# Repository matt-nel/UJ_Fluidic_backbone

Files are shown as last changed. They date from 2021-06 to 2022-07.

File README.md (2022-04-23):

# **UJ Fluidic Backbone**

This software provides a controller for low-cost, open-source chemistry equipment. The fluidic backbone uses Commanduino Arduino-based robots using Python scripts. The software provides an object-oriented interace that correlates to the equipment, broken down into module objects with attached device objects. 

The robot can be run manually using the GUI or by loading XDL documents that describe a chemical synthesis. 

https://croningroup.gitlab.io/chemputer/xdl/standard/index.html

The robot can be run in conjuction with the MC_Labserver (https://github.com/Pajables/MC_Labserver), which allows the user to send reactions to a number of attached robots and tracks reaction data. 

## **Installation**

To use the robot, we need to set up software set up on computer and an Arduino. I'll run through all of that here.

First, get the robot's software. On the Github page, click on the green button on the top right and select "Download Zip" from the menu. Extract the contents of that zip file to somewhere on your computer. Click in the address bar and copy the path to where you extracted the files.

### **Python**

The robot has been tested extensively with Python 3.8.5. You can install Python 3.8.5 using the link that follows. It is recommended that you add Python to your Path variables (Keep an eye on the options in the installer). 

https://www.python.org/downloads/release/python-385/

### **Robot software installation**

The easiest way to install the software is to use the `pip` tool in the command prompt (Windows) or terminal (Unix). Use the path we copied earlier for [PATH]. 

```
cd [PATH]
pip install .
```

### **Commanduino**

 Commanduino is a library created by the Cronin Group at the University of Glasgow for controlling Arduino microcontrollers using Python. This robot uses a modified version of the Commanduino library available at:

https://github.com/Pajables/commanduino

To install, download the zip and extract the files to a folder on your computer, I would recommend C:/Users/your_user_name/your_folder for Windows users. Like before, copy the address where you extracted the folder. Open a terminal window, you'll notice that the text to the left of the cursor shows the directory you're currently working within. We need to get the directory that contains commanduino. 

`cd [PATH] `

Now install using pip

`pip install .`

Commanduino is set up!

### **OpenCV** (optional)

OpenCV is a open-source C++ library for computer vision. Required if you will need a camera. 

Windows:

https://opencv.org/releases/

Linux:

Open a terminal and use your favourite package manager to install OpenCV:

`sudo apt install python3-opencv`

### **Arduino IDE and libraries**

To set up the firmware on the Arduino, first download the Arduino IDE at:

https://www.arduino.cc/en/software

The required libraries for the Arduino code can be found in the UJ_Fluidic_backbone repo under: 

`./fluidic_backbone_arduino/commanduino_libraries/`

Please copy the contents of that folder into your Arduino library folder. For Windows users, this is likely

`Documents/Arduino/libraries`

### **Arduino firmware**

Once the Arduino libraries are set up, use the Arduino IDE to upload the firmware within `./fluidic_backbone_arduino/`. Open the Fluidic_backbone_arduino.ino file, set the board and port settings using the tools menu, then click on Upload. This will set the Arduino up to send and receive commands using Commanduino. 

## First-time setup

To first configure the robot, please run the setup GUI. This program will allow you to configure the software for the specific hardware setup you are using.

1. Run `python setup_GUI.py` using the terminal.
2. If a button for an Arduino is available, click on that. Otherwise, write the name of the serial port you will be using in the field, and click "Accept".
3. Click on **"Configure modules"**, then enter the number of valves and syringes into the pop ups that appear.
4. The next screen will show the available valves. Each port has a dropdown where you can select the type of module that is connected to that port. For each port you have connected, select the corresponding item in the dropdown.
5. Once you have selected modules for each used port, click on the buttons for each used port to configure the module. The configuration options will change based on the module you have selected. Once configuration for the port is complete, the button will turn green.
6. Once you have configured all the ports, click **"Accept"**
7. In the main window, click **"Create config"**, then exit the or click "Run Fluidic Backbone" on the right hand side. 

Alternatively, open a terminal and use `cd` browse to the directory where you unzipped the UJ_Fluidic_backbone repo. Use the command `python main.py` to start the robot.

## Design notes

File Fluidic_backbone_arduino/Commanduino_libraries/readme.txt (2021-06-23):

Modified versions of the Arduino-CommandHandler and Arduino-Commandtools libraries.

Copy these files to your Arduino libraries folder to use them in the sketch.

For more information on installing libraries, see: http://www.arduino.cc/en/Guide/Libraries

Links to original repositories:

https://github.com/croningp/Arduino-CommandTools

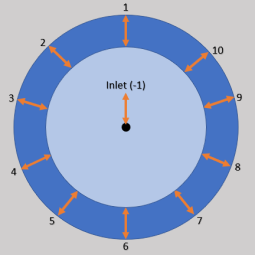
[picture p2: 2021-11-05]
src/UJ_FB/valve.png

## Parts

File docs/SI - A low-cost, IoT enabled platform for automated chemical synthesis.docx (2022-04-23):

Supplementary information: A low-cost, IoT enabled platform for automated chemical synthesis

Matthew Nela, Reinout Meijboom^b, and Andre L. Nela

aDepartment of Mechanical Engineering, University of Johannesburg, PO Box 524, Auckland Park 2006, Johannesburg, South Africa.

^bDepartment of Chemical Sciences, University of Johannesburg, PO Box 524, Auckland Park 2006, Johannesburg, South Africa. Tel.: +27 11 559 2367; Fax.: +27 11 559 2819. E-mail: andren@uj.ac.za

# 1. UJ_FB Design information

## 1.1 Bill of materials

Bill of materials
Part number | QTY | Description | Price (ea) | Total Price | Supplier | Product link
Robot
RB-01 | 1 | Arduino MEGA 2560 microcontroller board | R299.95 | R299.95 | 3D Printing Store | https://www.3dprintingstore.co.za/centurionstore/catalog/product/view/id/1909
RB-02 | 1 | RAMPS 1.4 3D printing expansion board | R199.95 | R199.95 | 3D Printing Store | https://www.3dprintingstore.co.za/centurionstore/catalog/product/view/id/967
RB-03 | 4 | DRV8825 stepper driver with heat sink | R99.95 | R399.80 | 3D Printing Store | https://www.3dprintingstore.co.za/centurionstore/catalog/product/view/id/1113
RB-04 | 1 | Teflon tubing 1/8 in' OD, 1/16 in' ID, 50 ft length | R2 652.65 | R2 652.65 | Analytical Sales & Services | https://www.analytical-sales.com/product/teflon-tubing-1-8-od-x-1-16-id-x-50/
RB-05 | 1 | Raspberry Pi 4 Model B 2GB Kit | R1 169.50 | R1 169.50 | PiShop | https://www.pishop.co.za/store/raspberry-pi_0/raspberry-pi4-model-b-2gb-blackgrey-official-case-essentials-kit-boxed-white-power-supply
RB-06 | 1 | Raspberry Pi Camera Board V2 | R499.00 | R499.00 | PiShop | https://www.pishop.co.za/store/raspberry-pi-camera-board-v2-8mp1080p?keyword=camera&category_id=0
RB-07 | 1 | Syringe pump assembly
RB-08 | 1 | Selector valve assembly
RB-09 | 2 | M3x8 mm bolt
| | | Total | R5 220.85
Valves
SV-01 | 2 | C25-618010 10 position manual selector valve for 1/4-28 fittings | R11 330.00 | R22 660.00 | Analytical Sales & Services | https://www.vici.com/cval/c25-8.php
SV-02 | 2 | NEMA 17 42x42x40 mm stepper motor, 1.8°/step, 1.7 A current/phase, 0.4 Nm holding torque | R269.95 | R539.90 | 3D Printing Store | https://www.3dprintingstore.co.za/centurionstore/stepper-motor-nema-17-x-40mm-1-8-deg-step.html
SV-02 | 2 | KY0024 Linear Hall-Effect sensor development board | R24.72 | R49.44 | Mantech | https://www.mantech.co.za/ProductInfo.aspx?Item=15M4835
SV-03 | 1 | 200 mm jumper leads | R0.54 | R0.54 | Mantech | https://www.mantech.co.za/ProductInfo.aspx?Item=15M5046-A
SV-04 | 10 | N35 Neodymium magnet disk | R5.04 | R50.40 | Mantech | https://www.mantech.co.za/ProductInfo.aspx?Item=15M0681-A
SV-05 | 8 | M3x10 pan head | R0.99 | R7.92 | RS Components | https://za.rs-online.com/web/p/machine-screws/0526956
SV-06 | 8 | M4 stainless steel hex nut | R1.08 | R8.64 | RS Components | https://za.rs-online.com/web/p/hex-nuts/0189579
SV-07 | 2 | M4x30 Cheese head steel slot | R1.34 | R2.68 | RS Components | https://za.rs-online.com/web/p/machine-screws/5466275
SV-08 | 6 | M4x35 Cheese head steel slot | R1.42 | R8.52 | RS Components | https://za.rs-online.com/web/p/machine-screws/9087769
SV-09 | 2 | Valve mount
SV-10 | 4 | ¼-28 Bolt
SV-11 | 2 | Driver gear
SV-12 | 2 | Driven gear
SV-13 | 4 | 6x21 mm round bar
SV-14 | 8 | M3x8 mm grub screw | R4.508 | R36.06 | RS Components | https://za.rs-online.com/web/p/grub-screws-set-screws/1247389
SV-15 | 4 | 6 x19x6 mm Deep groove ball bearing | R55.1 | R220.04 | RS Components | https://za.rs-online.com/web/p/ball-bearings/6189913/?sra=pstk
SV-16 | 2 | Gearbox bottom
SV-17 | 2 | Gearbox top
SV-18 | 8 | M3 hex nut | R0.34 | R4.76 | 3D Printing Store | https://za.rs-online.com/web/p/hex-nuts/0560293
| | | Total | R23 589.04
Syringe Pumps
SP-01 | 2 | NEMA 17 42x42x40 mm stepper motor, 1.8°/step, 1.7 A current/phase, 0.4 Nm holding torque | R269.95 | R539.90 | 3D Printing Store | https://www.3dprintingstore.co.za/centurionstore/stepper-motor-nema-17-x-40mm-1-8-deg-step.html
SP-02 | 2 | Mechanical endstop 90° version | R24.95 | R49.90 | 3D Printing Store | http://www.3dprintingstore.co.za/electronics/mechanical-endstop-90-version/
SP-03 | 2 | TCST2103 Gap Sensor with phototransistor output | R17.44 | R34.88 | Mantech | https://www.mantech.co.za/ProductInfo.aspx?Item=35M4257
SP-04 | 2 | LM393 dual voltage comparator | R11.72 | R23.44 | Mantech | https://www.mantech.co.za/ProductInfo.aspx?Item=15M6164
SP-05 | 4 | Stainless steel rod 6 mm diameter 140 mm | R9.11 | R36.44 | RS Components | https://za.rs-online.com/web/p/metal-bars-metal-rods/0682826/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
SP-06 | 2 | TR8x8 lead screw 115 mm | R50.00 | R100.00 | 3D Printing Store | https://www.3dprintingstore.co.za/centurionstore/catalog/product/view/id/1213
SP-07 | 4 | LM6UU linear bearing pair | R39.00 | R156.00 | 3D Printing Store | https://www.3dprintingstore.co.za/centurionstore/catalog/product/view/id/1009
SP-08 | 2 | Tr8x8 brass nut | R39.95 | R79.90 | 3D Printing Store | https://www.3dprintingstore.co.za/centurionstore/catalog/product/view/id/1166
SP-09 | 2 | Rigid coupling 5-8 mm | R69.95 | R139.90 | 3D Printing Store | https://www.3dprintingstore.co.za/centurionstore/catalog/product/view/id/1659
SP-10 | 20 | M3x20mm bolt | R0.85 | R17.00 | 3D Printing Store | https://za.rs-online.com/web/p/machine-screws/0560625
SP-11 | 14 | M3x6 mm bolt | R0.32 | R4.48 | 3D Printing Store | https://za.rs-online.com/web/p/machine-screws/0560580
SP-12 | 14 | M3 hex nut | R0.34 | R4.76 | RS Components | https://za.rs-online.com/web/p/hex-nuts/0560293
SP-13 | 2 | Hamilton 1010TLL Gastight syringe PTFE luer lock | R1 791.00 | R3 582.00 | Sigma Aldrich | https://www.sigmaaldrich.com/ZA/en/product/sial/21000u?context=product
SP-14 | 2 | Pump body | - | - | - | -
SP-15 | 2 | Pusher Block | - | - | - | -
SP-16 | 2 | Syringe holder | - | - | - | -
SP-17 | 2 | Slotted disk | - | - | - | -
SP-18 | 2 | M3x8 mm bolt | R0.6052 | R1.21 | RS Components | https://za.rs-online.com/web/p/machine-screws/9087661
| | | Total | R4 768.60
Reactor
RCT-01 | 1 | Rostock Delta MK3 Round heated bed | R329.95 | R329.95 | DIY Electronics | https://www.diyelectronics.co.za/store/beds-heaters/1532-rostock-delta-mk3-round-heated-bed.html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
RCT-02 | 2 | 12 V 4010 Axial Fan | R69.95 | R139.9 | DIY Electronics | https://www.diyelectronics.co.za/store/thermistors/630-thermistor-100k-1-ntc-pre-wired.html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
RCT-03 | 1 | 100K Thermistor | R24.95 | R24.95 | DIY Electronics | https://www.diyelectronics.co.za/store/thermistors/630-thermistor-100k-1-ntc-pre-wired.html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
RCT-04 | 4 | Neodymium N42 Rectangular Magnet | R14.95 | R59.80 | DIY Electronics | https://www.diyelectronics.co.za/store/magnets/1308-neodymium-n42-magnets-rectangular-10x7x2mm.html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
RCT-05 | 2 | Fan mount | - | - | - | -
RCT-06 | 12 | M3x12 mm bolt | R0.99 | 11.88 | RS Components | https://za.rs-online.com/web/p/machine-screws/0560697
| | | Total | R566.48

## 1.2 RAMPS Wiring and voltage comparator circuit

The setup software assumes these groups of pins have been used.

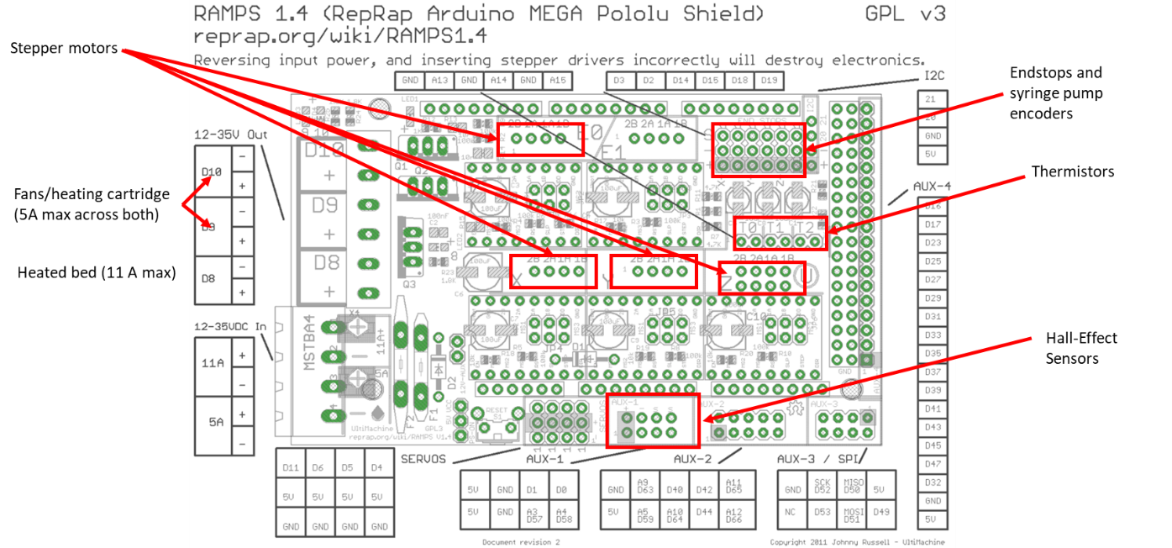
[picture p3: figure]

Figure 64: Wiring guide for RAMPS board

Figure 69 shows the circuit diagram for the syringe pump encoder voltage comparator. When the comparator output is off, the input voltage, Vin, must increase to above 4 V turn on the comparator output. When the comparator output is on, the output will only turn off once Vin drops below 2.7 V. This hysteresis effectively prevents oscillations from incrementing the counter. Details regarding the design are presented in Appendix A.

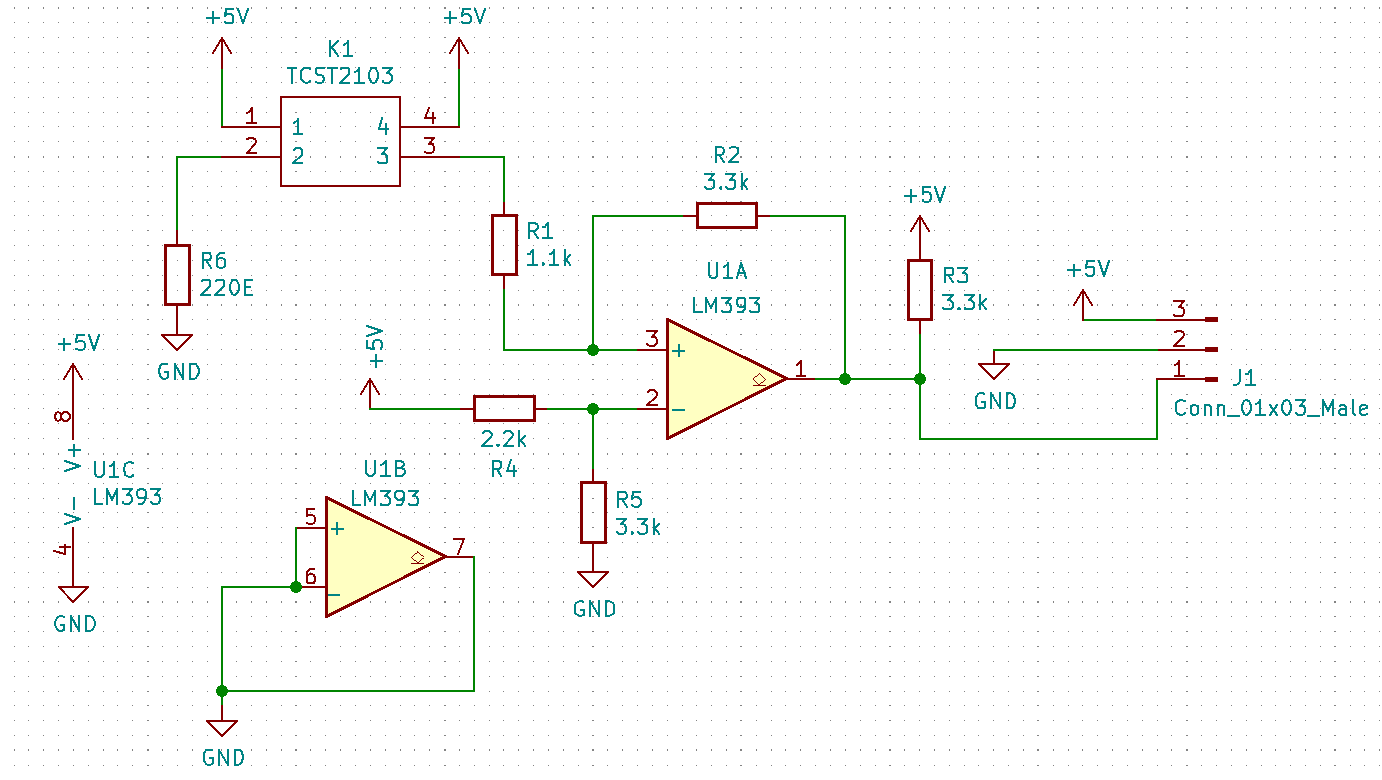
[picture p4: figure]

Figure 69: Schematic for the syringe pump encoder circuit

## 1.3 Assembly drawings

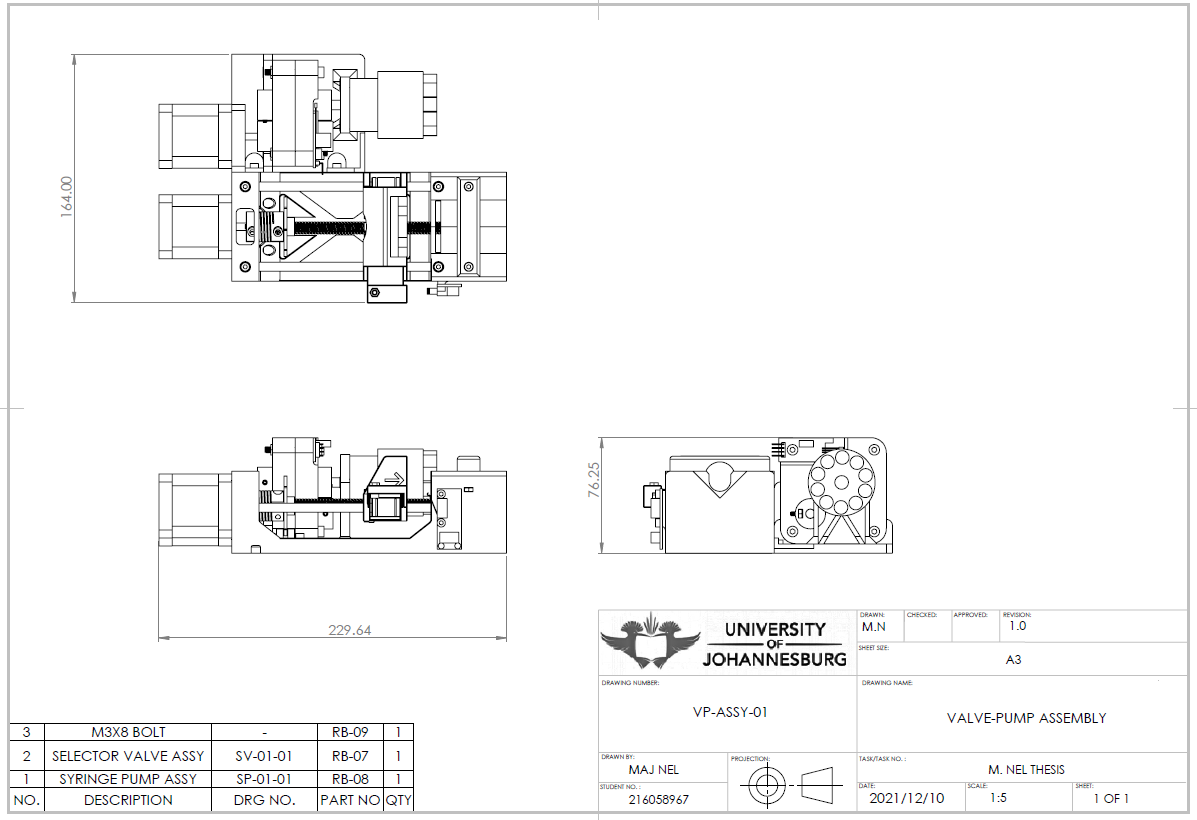
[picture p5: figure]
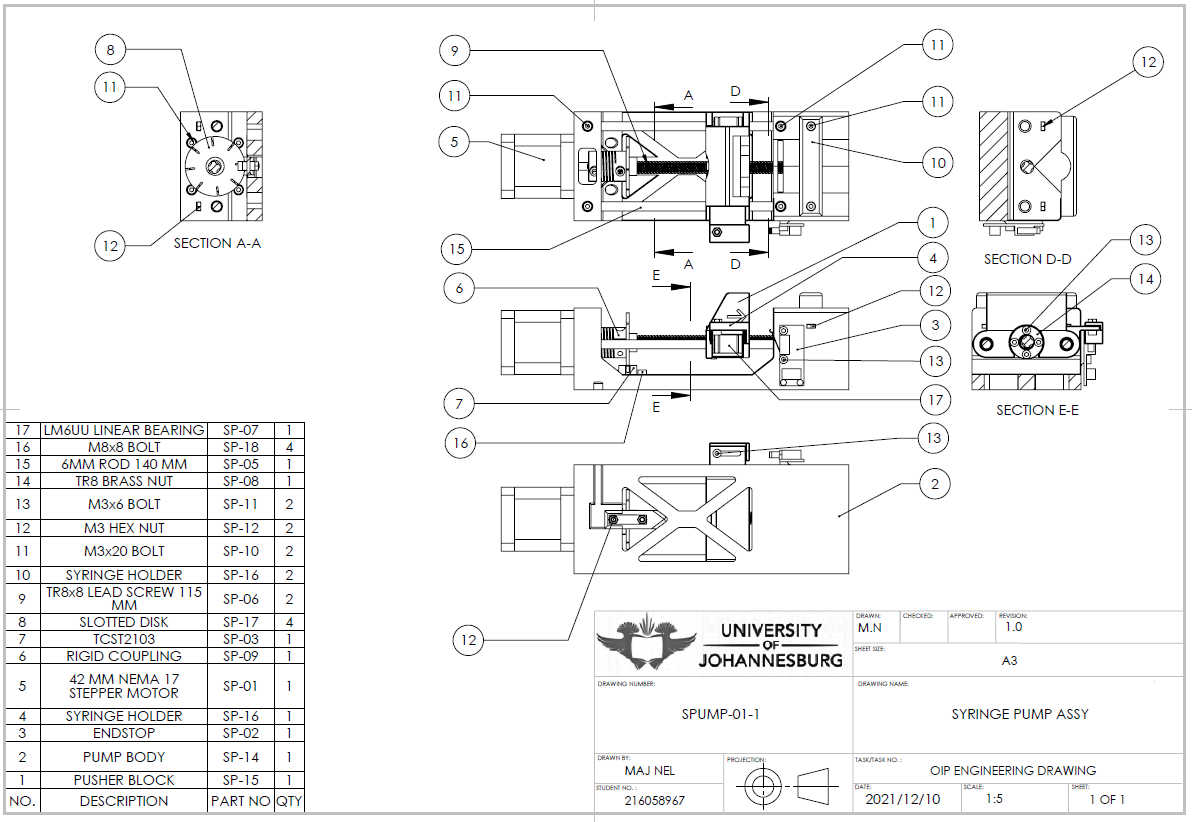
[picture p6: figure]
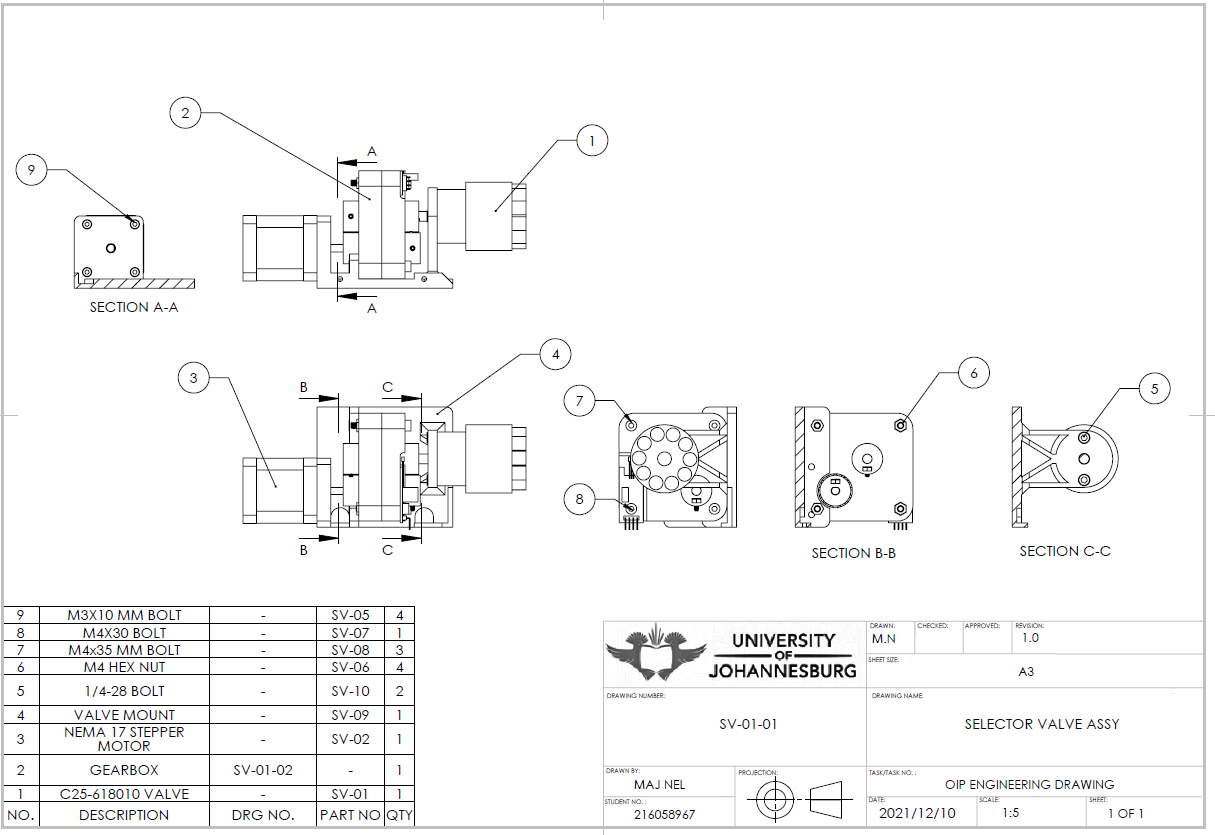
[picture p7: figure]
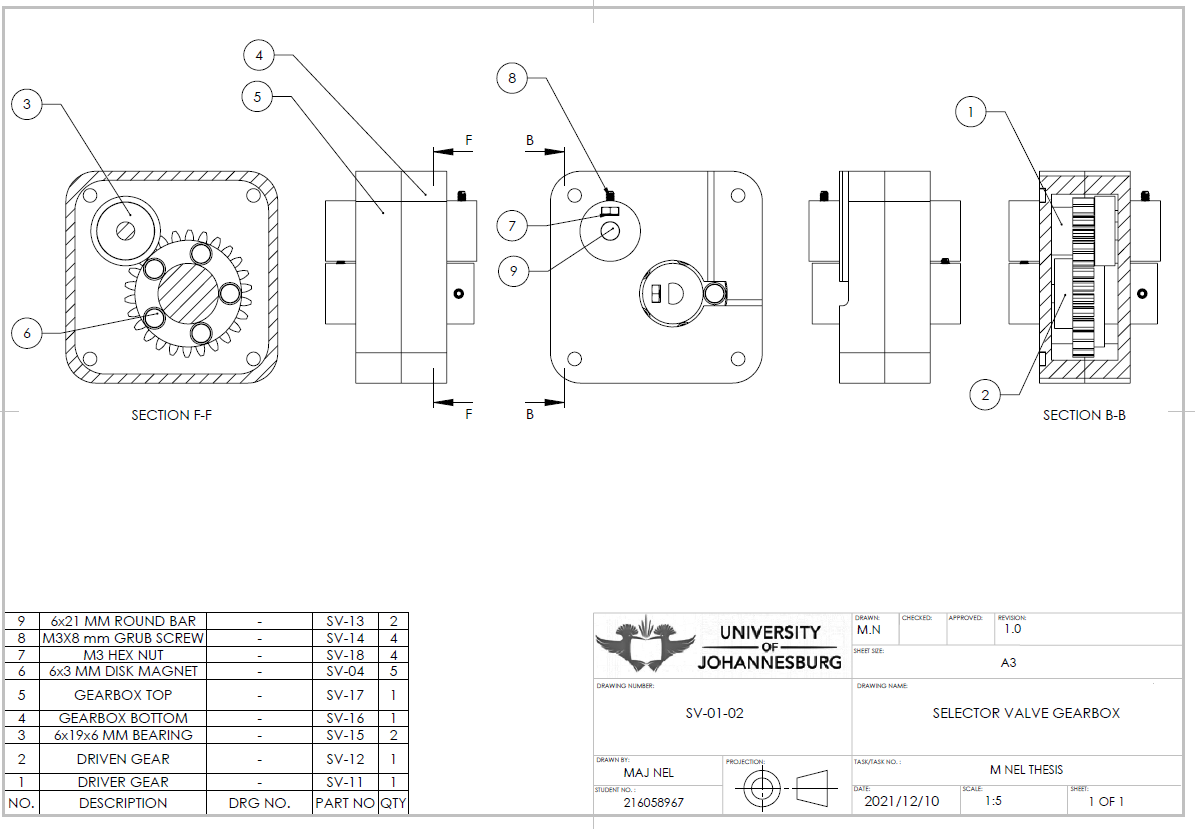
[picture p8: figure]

# 2. Aspirin synthesis

## 2.1 Materials and methods

PPE, including a lab coat, gloves, and goggles, were worn when working on the robot. Concentrated sulphuric acid is highly corrosive and should be handled with care. The reaction required the following equipment:

- Computer with UJ_FB software
- Arduino and RAMPS
- Syringe pump
- Selector valve
- Reactor
- Condenser
- Stirrer hotplate
- Two magnetic stirrer bars
- Round-bottom flask
- Four Schott bottles
- Reagents:
  - Deionised water
  - Acetic anhydride
  - Sulphuric acid
- Conical flask for waste
- Gravity chromatography column
- A beaker containing ice water
- 1/8 in’ Teflon tubing
- PPE
  - Goggles
  - Gloves
  - Lab coat

Before the experiment, the following preliminary steps were followed:

1. Flash the firmware to the Arduino Mega.
2. Connect the syringe pump, selector valve, and reactor to the RAMPS board. Instructions are included in Appendix A.
3. Write and check the XDL for the synthesis.
4. Clean the valve and check that all fasteners on the actuator are secure.
5. Suspend the syringe pump vertically using a retort stand.
6. Prepare an oil bath for the round-bottom flask and place it on the reactor module
7. Suspend the round-bottom flask in the oil bath using a retort stand. Take care when clamping the round-bottom flask to avoid damaging the glass.
8. Attach the condenser to the round-bottom flask and turn on the condenser pump.
9. Prepare tubing for the reactor and filter top, measure and record the length of these tubes.
10. Attach tubing to the reactor, waste, filter top, and filter bottom.
11. Drill 3.2 mm holes in the lids of the Schott bottles for the reagents
12. Attach the tubing to the reagents, concentrated sulphuric acid, and deionised water. Prime each of these lines and flush volume within the syringe to waste.
13. Connect stirrer hotplate to power, place beaker with ice water on top of the plate, then hold gravity chromatography column within the water using a retort stand.
14. Place one stirrer bar into the round-bottom flask and another into the gravity chromatography column.
15. Connect the Arduino to the computer and use Python to run the setup_GUI.py script to set up the robot.

The method for the experiment is as follows:

1. Weigh 5 g of salicylic acid using a weighing scale.
2. Place the salicylic acid into the round bottom flask using wax paper as a funnel.
3. Start stirring the stirrer hotplate at 500 RPM.
4. Use Python to run main.py within the UJ_Fluidic_backbone folder.
5. Load the XDL into the server or the UJ_FB software.
6. Wait until the XDL execution has paused.
7. Transfer the products into the gravity chromatography column using a spatula.
8. Resume the XDL execution.
9. Wait until the XDL execution is complete.

The XDL document contains the following steps for the robot:

1. Preheat the reactor to 70 °C.
2. Start stirring at 4000 RPM.
3. Transfer 6 ml of acetic anhydride to the reactor (round-bottom flask).
4. Transfer 0.5 ml of sulphuric acid to the reactor.
5. Heat at 70 °C for 15 minutes.
6. Pause until the user moves products to the filter.
7. Add 10 ml of deionised water to the top of the filter.
8. Wait 5 minutes for crystallisation to occur.
9. Remove 10 ml of fluid from the bottom of the filter to waste.
10. Add 5 ml of water to the top of the filter.
11. Remove 8 ml of water from the bottom of the filter to waste.
12. Repeat steps 10-11 twice.

## 2.2 Aspirin synthesis XDL

<?xdl version="1.0"?>

<XDL>

<Synthesis>

<Metadata>

</Metadata>

<Hardware>

<Component id="Reactor1" type="reactor"/>

</Hardware>

<Parameters>

</Parameters>

<Reagents>

<Reagent id="salicylic_acid" />

<Reagent id="acetic_anhydride" />

<Reagent id="sulphuric_acid" />

<Reagent id="water" />

</Reagents>

<Procedure>

<!--Preheat the reactor-->

<HeatChillToTemp

vessel="reactor"

temp="70 °C" />

<!--Maintain reactor temperature-->

<StartHeatChill

vessel="reactor"

temp="70 °C"/>

<!--Maintain stirring-->

<StartStir

vessel="reactor"

stir_speed="4000 rpm"/>

<!--Add bulk of acetic anhydride-->

<Add

reagent="acetic_anhydride"

vessel="Reactor1"

volume="6 ml" />

<!--Add sulphuric acid-->

<Add

reagent="sulphuric_acid"

vessel="reactor"

volume="0.5 ml" />

<!--Maintain at temp for specified time-->

<HeatChill

vessel="Reactor1"

temp="70 °C"

time="900 s"/>

<Wait

time='0s'

comments="wait_user, wait_reason(transfer to filter)" />

<--! add water to top of filter for crystallisation -->

<Add

reagent="water"

vessel="flask0"

volume="10 ml"

/>

<!--Wait while cooling-->

<StopHeatChill

vessel="reactor1" />

<Wait

time="300 s"

comments="wait_reason(crystallisation)" />

<!-- wash the products -->

<Transfer

from_vessel="filter_bot"

to_vessel="waste"

volume="10 ml" />

<Add

reagent="water"

vessel="filter_top"

volume="5 ml" />

<Transfer

from_vessel="filter_bot"

to_vessel="waste"

volume="8 ml" />

<Add

reagent="water"

vessel="filter_top"

volume="5 ml" />

<Transfer

from_vessel="filter_bot"

to_vessel="waste"

volume="8 ml" />

<Add

reagent="water"

vessel="filter_top"

volume="5 ml" />

<Transfer

from_vessel="filter_bot"

to_vessel="waste"

volume="8 ml" />

</Procedure>

</Synthesis>

</XDL>

## 2.3 Aspirin reaction data

NMR spectrum

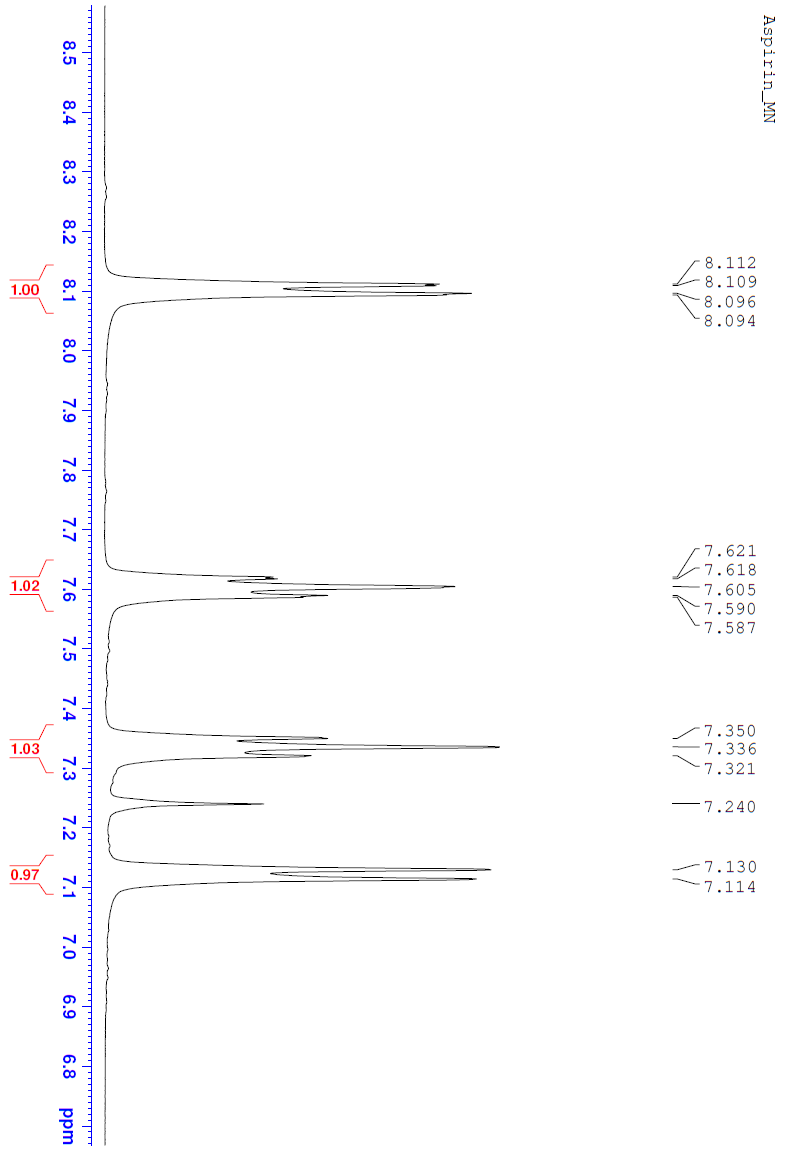
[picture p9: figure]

Nuclear Magnetic Resonance Spectroscopy (1H and 13C{H}) Analysis of Aspirin

¹H-NMR (500 MHz, CDCl3) δ ppm: 2.33 (s, CH3), 7.122 (d, aromatic H), 7.335 (t, aromatic H), 7.604 (m, aromatic H), 8.103 (dd, OH). ¹³C{H}-NMR (125 MHz, CDCl3) δ ppm: 21.20 (s, CH3), 122.50 (s, aromatic C), 124.25 (s, aromatic C), 126.36 (s, aromatic C), 132.73 (s, aromatic C), 135.05 (s, aromatic C), 151.53 (s, aromatic C), 169.88 (d, COOH)

# 3. Collaborative azo dye search

## 3.1 Materials and methods

Stock solutions were prepared using a solvent comprised of 0.01 M acetone and 1.7 M HCl in a 1:1 ratio. 0.01 M sodium nitrite solution was prepared in water and 0.5 M sodium hydroxide in water. The following equipment was used for the azo dye syntheses:

Table 3: Equipment for azo dye reactions

QTY | Item
3 | Raspberry Pi 4
3 | Raspberry Pi camera module
3 | Arduino and RAMPS
6 | DRV8825 stepper drivers
3 | Syringe pump module
3 | Selector valve module
3 | Stirrer module
3 | Sample vial holder
3 | 100 ml Schott bottle
2 | 250 ml Schott bottle
2 | 1 l Schott bottle
3 | Magnetic stirrer bar
1 | 15 m of 1/8 in’ diameter tubing
1 | 10 cm of 1/16 in’ diameter tubing
4 | 3D printed tiles for Schott bottles
1 | 100 ml aniline solution
1 | 100 ml 4-nitroaniline solution
1 | 100 ml 1-naphthylamine solution
1 | 250 ml sodium hydroxide solution
1 | 250 ml sodium nitrate solution
2 | Retort stands

The following steps were followed to set up for the reaction:

1. Flash the firmware to the Arduino Mega.
2. Install UJ_FB, Commanduino, and OpenCV on the Raspberry Pi.
3. Connect the syringe pump, selector valve, and reactor to the RAMPS board. Instructions are included in Appendix A.
4. Write and check the XDL for the synthesis.
5. Clean the valve and check that all fasteners on the actuator are secure.
6. Suspend the syringe pump vertically using a retort stand.
7. Drill four 3.2 mm holes in the lids of each Schott bottle
8. Drill one 3.2 mm hole in each of the sample vials
9. Prepare the tubing for the sample vials, measuring the length of the tubing.
10. Prepare and attach tubing for the reagents, deionised water, and waste.
11. Place each sample vial into a 3D printed holder with a sheet of white paper backing the sample vial.
12. Place a short length of 1/16 in tubing in the end of the tubes to the reactor.
13. Prime the tubing to the reagents and deionised water.
14. Secure the camera module mount to the table.
15. Run the setup_GUI.py script to set up the UJ_FB software.
16. Focus the cameras using included tool and video captured from OpenCV.

A 3D printed holder was designed to secure the sample vial without obscuring the solution within the vial. The experimental setup for the syntheses is shown in Figure 63. The reagents, water, and waste were set up between two rows of robots. The reactions were distributed across three discrete robots by installing the UJ_FB software on three Raspberry Pis connected to an instance of the MC_Labserver software running on a fourth Raspberry Pi.

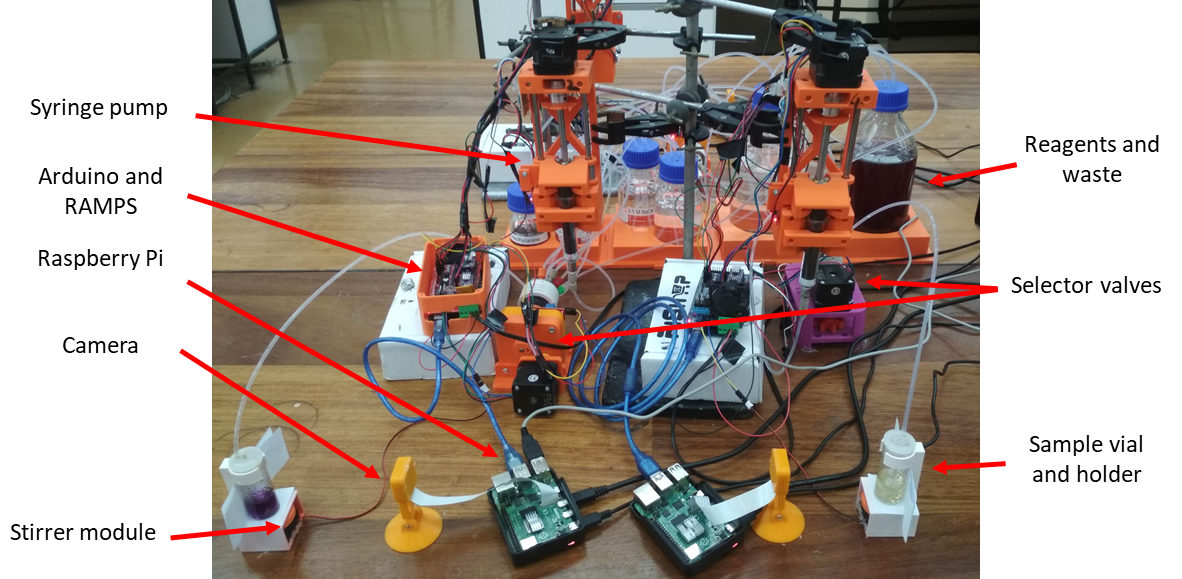
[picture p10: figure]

Figure 1: Experimental setup for azo dye synthesis

Common reagent bottles were set up that each robot could access independently. The selector valve for each robot was plumbed to each of the reagents and to a common waste bottle. Reactions were performed in sample vials held in place over a fan-based magnetic stirrer using a 3D printed holder. While the reactions were running, the reagents were refilled as required. The waste bottle was replaced whenever it became full.

The following process was followed to carry out the reactions:

1. Upload a batch of reactions as a CSV file to the server
2. Set up an SSH instance connecting to the Raspberry Pi
3. Start a Python shell and create an instance of the Manager
1. Start stirring at 2500 RPM.
2. Add X ml of reagent one to the sample vial.
3. Add Y ml of sodium nitrite.
4. Stir for 120 s.
5. Pause stirring, take image one and upload to the server, then resume stirring.
6. Add Z ml of reagent two to the sample vial.
7. Wait 30 min for reaction completion.
8. Pause stirring, take image two and upload to the server, then resume stirring.
9. Transfer 5 ml of products from sample vial to waste.
10. Add 5ml of deionised water to the sample vial
11. Pause stirring, take image three and upload to the server, then resume stirring.
12. Add 2 ml of sodium hydroxide to the sample vial.
13. Pause stirring, take image four and upload to the server, then resume stirring.
14. Flush the reactor and rinse it three times.

## 3.2 Collaborative azo dye search XDL

<?xdl version="1.0"?>

<XDL>

<Synthesis>

<Metadata

description="XDL for the azo-dye collaborative reactions"

img_processing="azo">

</Metadata>

<Hardware>

<Component id="Reactor1" type="reactor"/>

</Hardware>

<Parameters>

</Parameters>

<Reagents>

<Reagent id="1 naphthylamine" />

<Reagent id="nitroaniline" />

<Reagent id="aniline" />

<Reagent id="sodium nitrate" />

<Reagent id="water" />

<Reagent id="sodium hydroxide" />

</Reagents>

<Procedure>

<!--Maintain stirrring-->

<StartStir

vessel="reactor"

stir_speed="2500 rpm"/>

<!-- reagent1 -->

<Add

reagent = "1 naphthylamine"

vessel = "reactor"

volume = ""

step_param0 = "param_0" />

<Add

reagent = "nitroaniline"

vessel = "reactor"

volume = ""

step_param0 = "param_1" />

<Add

reagent = "aniline"

vessel = "reactor"

volume = ""

step_param0 = "param_2" />

<Add

reagent="water"

vessel="waste"

volume="1 ml" />

<!-- sodium nitrate -->

<Add

reagent = "sodium nitrate"

vessel = "reactor"

volume = ""

step_param0 = "param_3" />

<Add

reagent="water"

vessel="waste"

volume="1 ml" />

<Wait

time = "120 s"

comments = "wait_reason(mixing)" />

<StopStir

vessel="reactor1" />

<Wait

time= "0 s"

comments="Picture1" />

<StartStir

vessel="reactor1"

stir_speed="2500 rpm" />

<!-- reagent2 -->

<Add

reagent = "1 naphthylamine"

vessel = "reactor"

volume = ""

step_param0 = "param_4" />

<Add

reagent = "nitroaniline"

vessel = "reactor"

volume = ""

step_param0 = "param_5" />

<Add

reagent = "aniline"

vessel = "reactor"

volume = ""

step_param0 = "param_6" />

<Add

reagent="water"

vessel="waste"

volume="1 ml" />

<!-- wait 30 min for reaction completion -->

<Wait

time= "30 min"

comments = "wait_reason(waiting for reaction completion)" />

<StopStir

vessel="reactor1" />

<Wait

time="20 s"

comments="Picture2" />

<StartStir

vessel="reactor1"

stir_speed="2500 rpm" />

<!-- Transfer 4.4 ml of products to waste for dilution (assume we've lost ~ 0.6 ml to residue in syringe-->

<Transfer

from_vessel="reactor"

to_vessel="waste"

volume="4.4 ml" />

<!-- dilute to 1/6 parts -->

<Add

reagent="water"

vessel="reactor"

volume="5 ml" />

<StopStir

vessel="reactor" />

<Wait

time= "20 s"

comments="Picture3" />

<StartStir

vessel="reactor"

stir_speed="2500 rpm" />

<!-- Add base -->

<Add

reagent="sodium hydroxide"

vessel="reactor"

volume="2 ml" />

<StopStir

vessel="reactor" />

<Wait

time= "20 s"

comments= "Picture4" />

<StartStir

vessel="reactor"

stir_speed="2500 rpm" />

<!-- empty reactor -->

<Transfer

from_vessel="reactor"

to_vessel="waste"

volume="8 ml" />

<!-- wash 1 -->

<Add

reagent="water"

vessel="reactor"

volume="8 ml" />

<Transfer

from_vessel="reactor"

to_vessel="waste"

volume="8 ml" />

<!-- wash 2 -->

<Add

reagent="water"

vessel="reactor"

volume="8 ml" />

<Transfer

from_vessel="reactor"

to_vessel="waste"

volume="8 ml" />

<!-- wash 3 -->

<Add

reagent="water"

vessel="reactor"

volume="8 ml" />

<Transfer

from_vessel="reactor"

to_vessel="waste"

volume="15 ml" />

<StopStir

vessel="reactor" />

</Procedure>

</Synthesis>

</XDL>
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

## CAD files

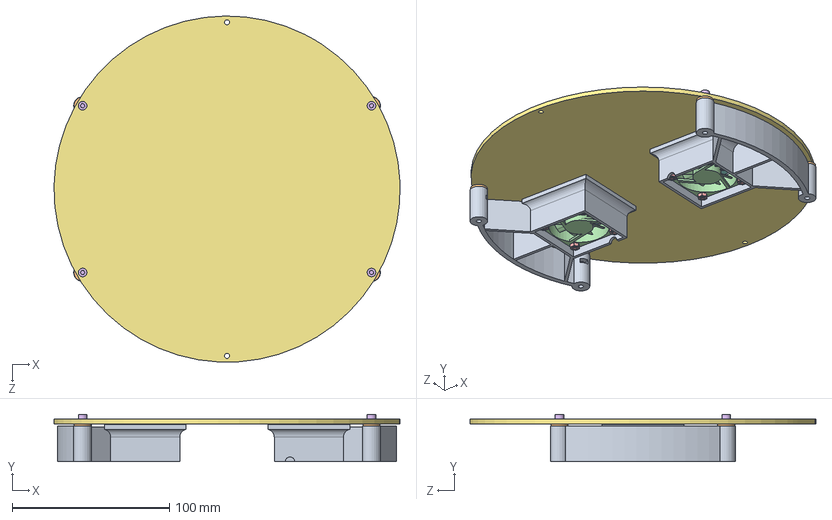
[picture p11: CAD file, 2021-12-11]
CAD_files/reactor/reactor 0.2.SLDASM
219.9 x 30.0 x 219.9 mm
reactor stand with fan x 2
PTFE washer x 4
ptfe fan spacer x 2
fan x 2
M3x2.4mm Hex Nut x 12
M3x0.5 12mm x 12
reactor plate
fan magnet mount rect 2 x 2
n42 rect magnet x 4

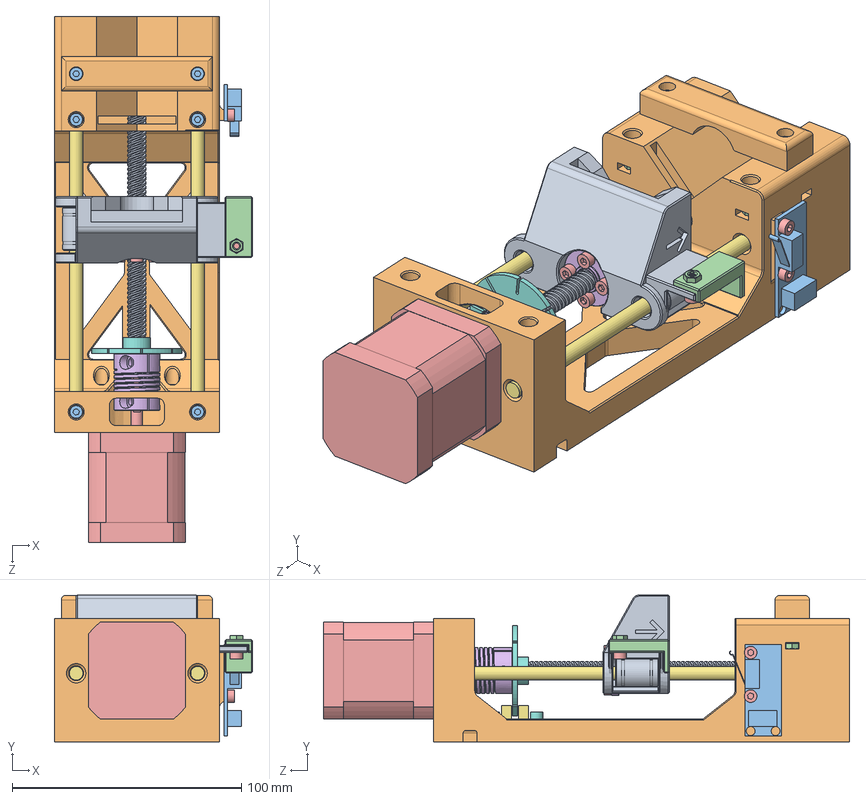
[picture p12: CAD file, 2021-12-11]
CAD_files/syringe_pump/Glass_syringe_pump.SLDASM
86.5 x 64.1 x 229.6 mm
carriage_v2
pump base
endstop
adjustable_endstop_arm
Nema 17 Stepper Motor
Flexible Coupling 5mm x 8mm
gap_sensor
slotted_wheel
tr8x8 115 mm
syringe_holder
M3x0.5 20mm x 10
M3x2.4mm Hex Nut x 9
M3x0.5 6mm x 7
Trapezoidal lead screw Nut tr8x8-4
6mm rod x 2
M3x0.5 8mm x 2
LM6UU x 2

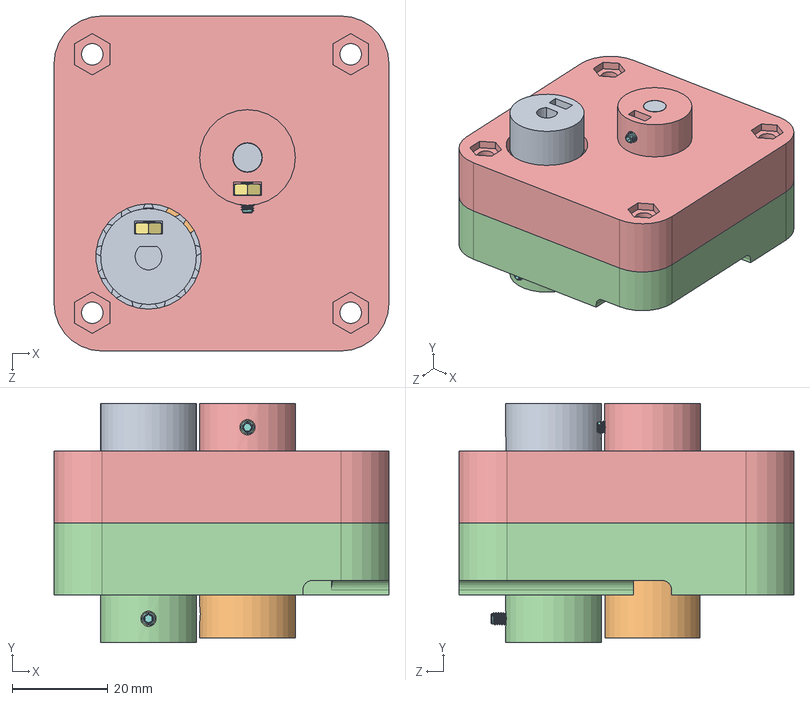
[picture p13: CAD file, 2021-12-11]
CAD_files/selector_valve/gearbox.SLDASM
70.0 x 50.0 x 70.0 mm
Driver gear 13T
Driven gear 26T
bearing x 2
gearbox_bottom
gearbox_top
magnet x 5
M3x2.4mm Hex Nut x 4
grub x 4
6mm rod 21mm x 2

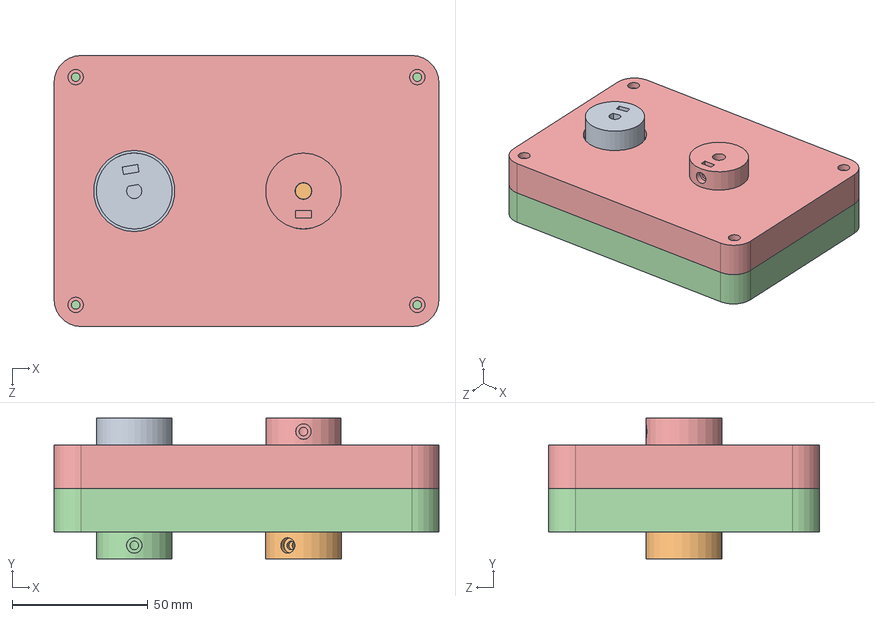
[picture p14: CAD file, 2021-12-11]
CAD_files/selector_valve/Assem1.SLDASM
142.0 x 52.0 x 100.0 mm
Driver gear 13T
Driven gear 26T
bearing x 2
gearbox_bottom
gearbox_top

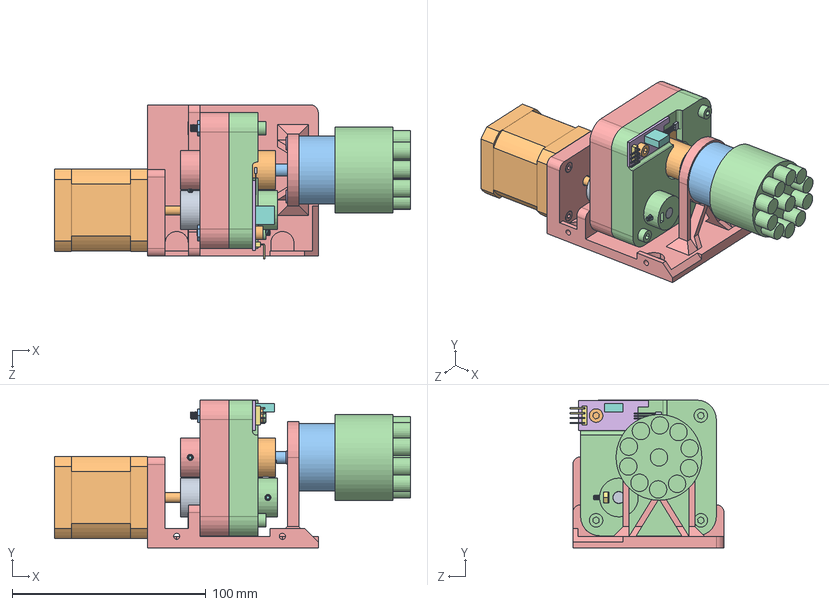
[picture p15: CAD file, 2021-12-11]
CAD_files/selector_valve/valve_gearbox.SLDASM
183.5 x 76.3 x 79.5 mm
Driver gear 13T
Driven gear 26T
bearing x 2
gearbox_bottom
gearbox_top
magnet x 5
M3x2.4mm Hex Nut x 4
grub x 4
6mm rod 21mm x 2
Nema 17 Stepper Motor
Valve base
Valve top
valve_gearbox_mount_vici
PCB
RA 2.54mm header
Potentiometer
49E722
m4x30
m4 nut x 4
m4x35 x 3
M3x0.5 10mm x 4

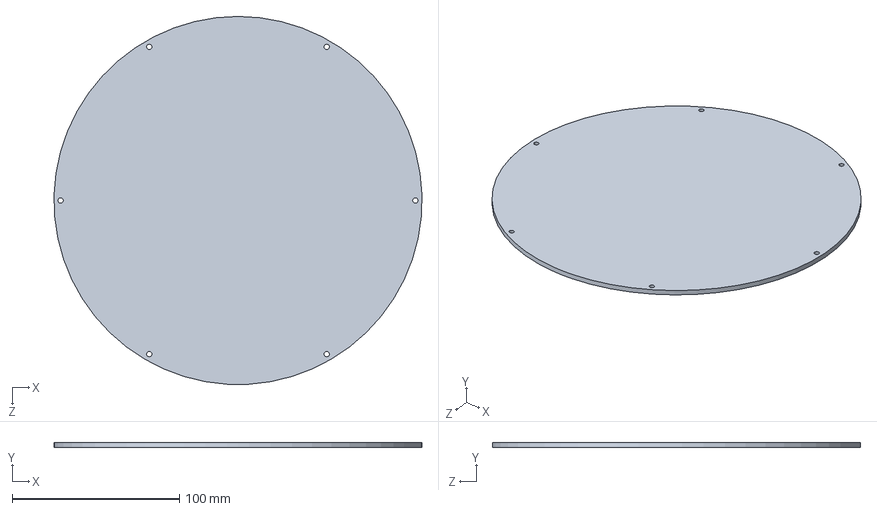
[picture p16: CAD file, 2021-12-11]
CAD_files/reactor/reactor plate.SLDPRT
219.9 x 3.00 x 220.0 mm

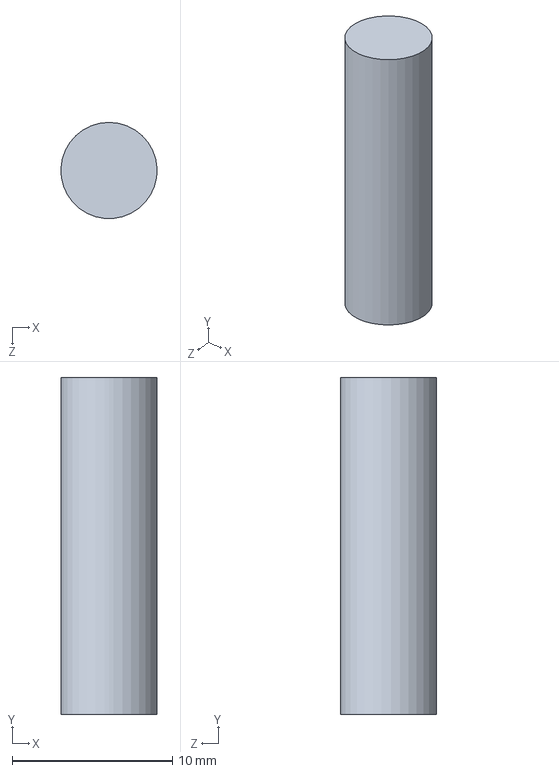
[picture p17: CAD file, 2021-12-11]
CAD_files/selector_valve/6mm rod 21mm.SLDPRT
5.99 x 21.0 x 6.00 mm

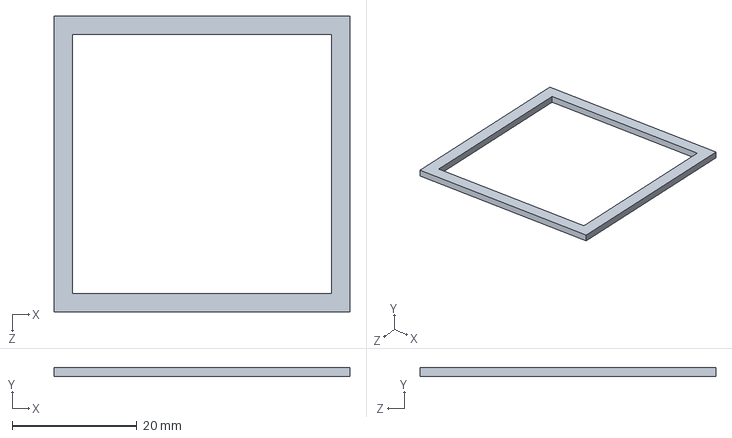
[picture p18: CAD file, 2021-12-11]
CAD_files/reactor/ptfe fan spacer.SLDPRT
47.5 x 1.50 x 47.5 mm

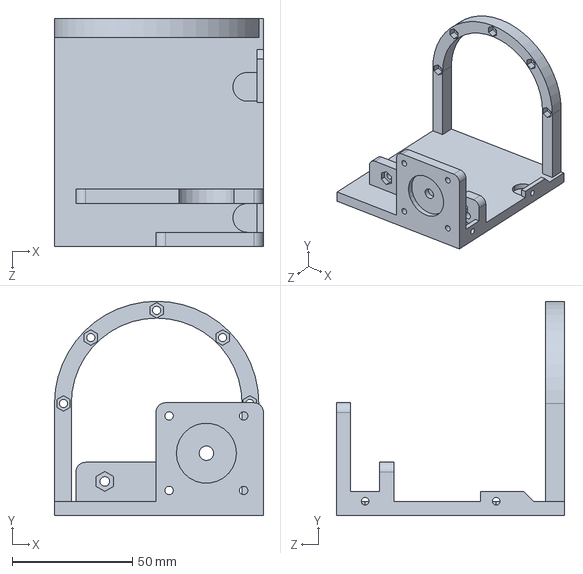
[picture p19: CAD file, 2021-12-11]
CAD_files/selector_valve/valve_gearbox_mount_3dp.SLDPRT
86.9 x 89.2 x 95.0 mm

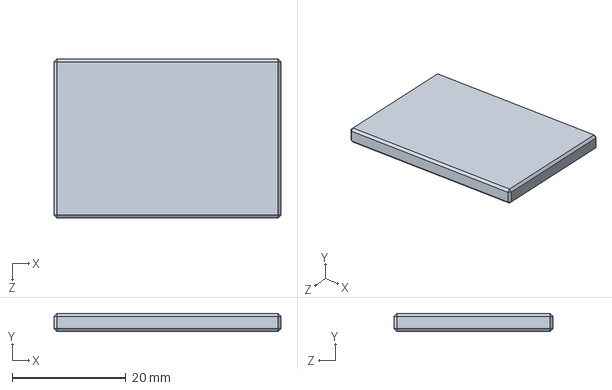
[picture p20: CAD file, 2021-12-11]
CAD_files/syringe_pump/disposable syringe adapter.SLDPRT
40.0 x 3.20 x 28.0 mm

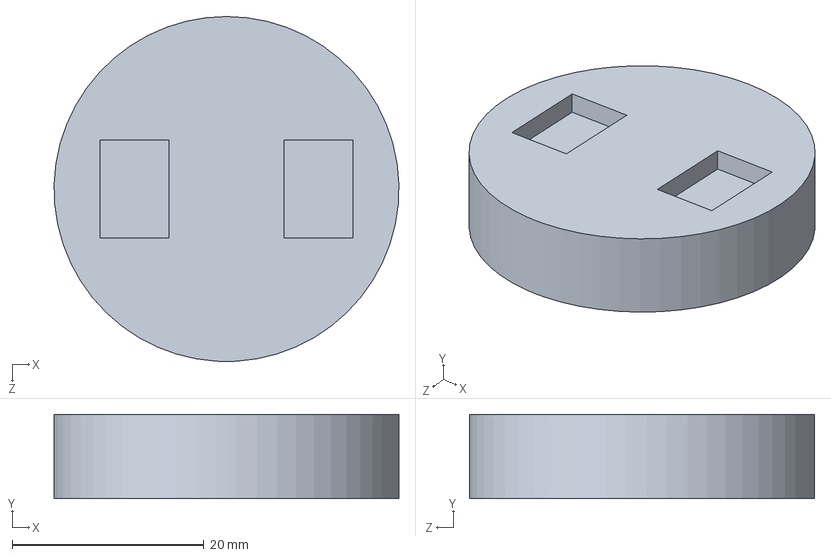
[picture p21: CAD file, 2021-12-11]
CAD_files/reactor/fan magnet mount rect 2.SLDPRT
36.0 x 8.80 x 36.0 mm

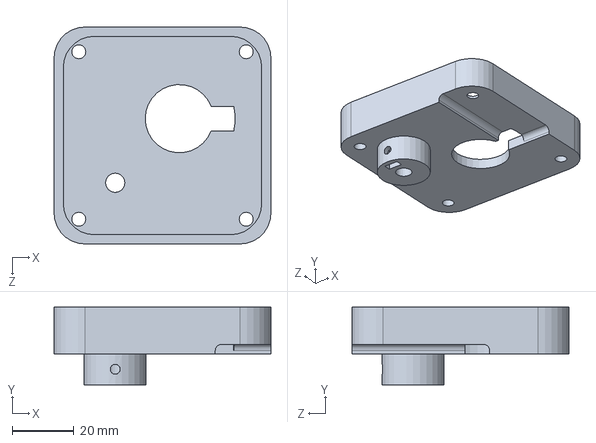
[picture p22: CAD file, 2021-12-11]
CAD_files/selector_valve/gearbox_bottom.SLDPRT
70.0 x 25.0 x 70.0 mm

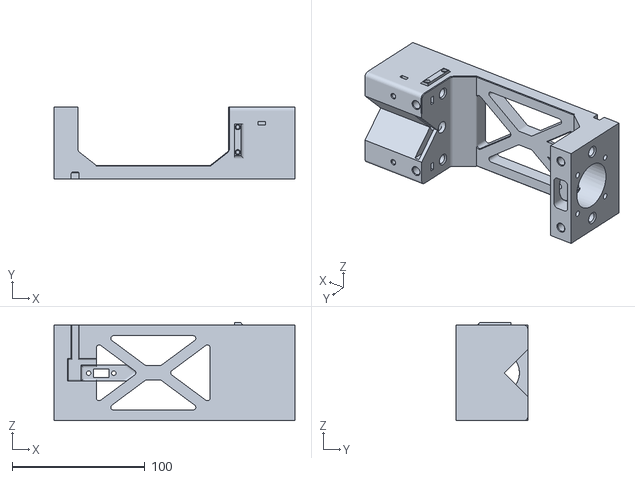
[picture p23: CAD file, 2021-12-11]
CAD_files/syringe_pump/pump base.STL
181.6 x 54.0 x 74.0

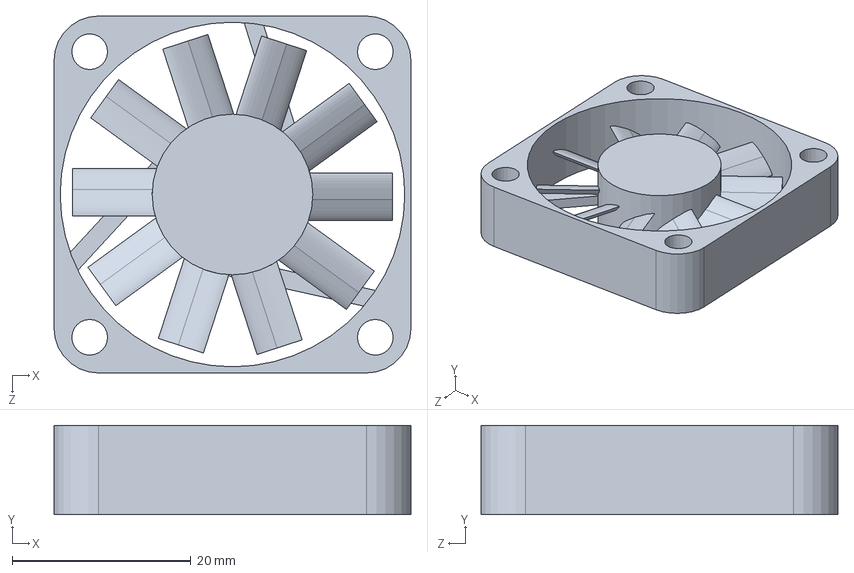
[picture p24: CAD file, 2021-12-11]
CAD_files/reactor/fan.SLDPRT
40.0 x 10.0 x 40.0 mm

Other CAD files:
CAD_files/syringe_pump/carriage.SLDPRT
CAD_files/selector_valve/valve_gearbox_mount.SLDPRT
CAD_files/syringe_pump/syringe_holder_18mm.SLDPRT
CAD_files/selector_valve/6mm rod.SLDPRT
CAD_files/reactor/M3x0.5 12mm.SLDPRT
CAD_files/reactor/M3x2.4mm Hex Nut.SLDPRT
CAD_files/reactor/PTFE washer.SLDPRT
CAD_files/reactor/fan magnet mount rect 2.STL
CAD_files/reactor/n42 rect magnet.SLDPRT
CAD_files/reactor/reactor stand with fan.SLDPRT
CAD_files/reactor/reactor stand with fan.STL
CAD_files/selector_valve/8-32-8.SLDPRT
CAD_files/selector_valve/Driven gear 25T.SLDPRT
CAD_files/selector_valve/Driven gear 26T 8mm shaft.SLDPRT
CAD_files/selector_valve/Driven gear 26T 8mm shaft.STL
CAD_files/selector_valve/Driven gear 26T.SLDPRT
CAD_files/selector_valve/Driven gear 26T.STL
CAD_files/selector_valve/Driver gear 13T.SLDPRT
CAD_files/selector_valve/Driver gear 13T.STL
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

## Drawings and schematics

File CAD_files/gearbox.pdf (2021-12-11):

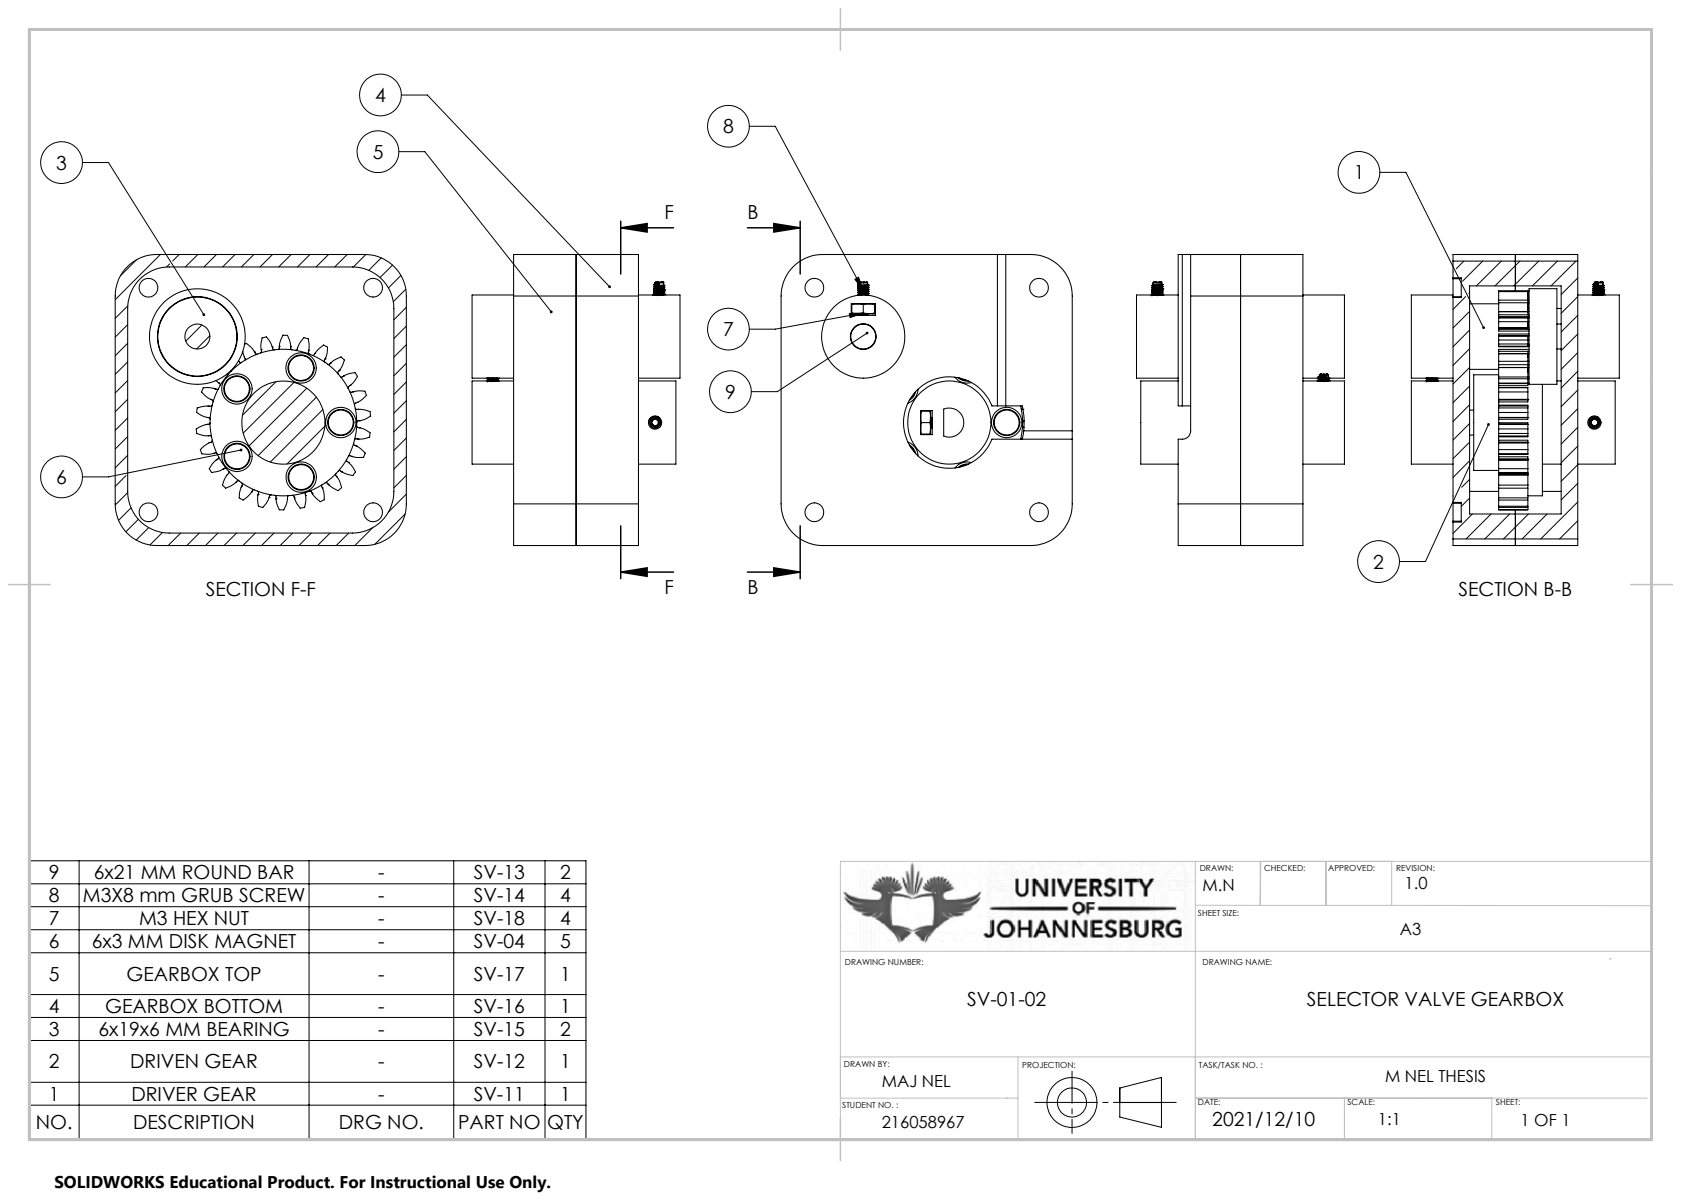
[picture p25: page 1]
SECTION B-B; SECTION F-F; 6x21 MM ROUND BAR; M3X8 mm GRUB SCREW; M3 HEX NUT; 6x3 MM DISK MAGNET; GEARBOX TOP; DRAWN BY:; PROJECTION:; STUDENT NO. :; DRAWING NAME:; MAJ NEL; M NEL THESIS; DRAWING NUMBER:; SHEET SIZE:; SELECTOR VALVE GEARBOX

4 | GEARBOX BOTTOM | - | SV-16 | 1
3 | 6x19x6 MM BEARING | - | SV-15 | 2
2 | DRIVEN GEAR | - | SV-12 | 1
1 | DRIVER GEAR | - | SV-11 | 1
NO. | DESCRIPTION | DRG NO. | PART NO QTY

TASK/TASK NO. :

SOLIDWORKS Educational Product. For Instructional Use Only.

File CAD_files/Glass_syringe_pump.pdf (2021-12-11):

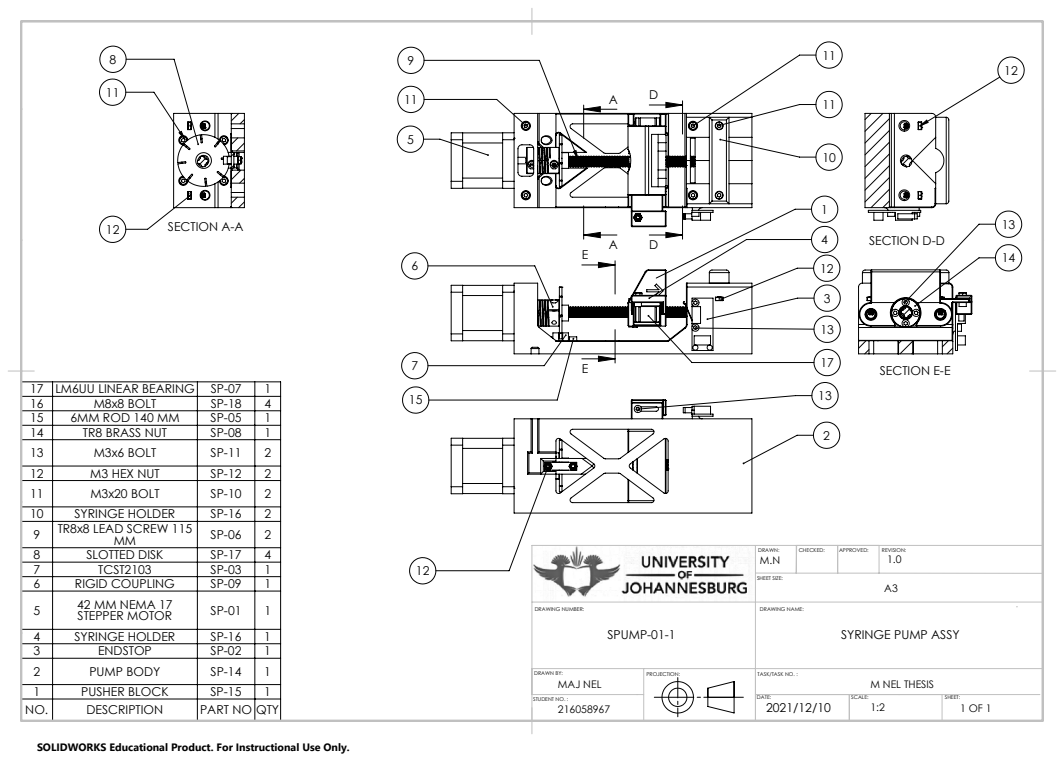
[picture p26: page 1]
SECTION A-A; SECTION D-D; SECTION E-E; SLOTTED DISK; STUDENT NO. :; SHEET SIZE:

17 | LM6UU LINEAR BEARING | SP-07 | 1
16 | M8x8 BOLT | SP-18 | 4
15 | 6MM ROD 140 MM | SP-05 | 1
14 | TR8 BRASS NUT | SP-08 | 1
13 | M3x6 BOLT | SP-11 | 2
12 | M3 HEX NUT | SP-12 | 2
11 | M3x20 BOLT | SP-10 | 2
10 | SYRINGE HOLDER | SP-16 | 2
9 | TR8x8 LEAD SCREW 115 MM | SP-06 | 2

7 | TCST2103 | SP-03 | 1
6 | RIGID COUPLING | SP-09 | 1
5 | 42 MM NEMA 17 STEPPER MOTOR | SP-01 | 1

DRAWING NUMBER: SPUMP-01-1 | DRAWING NAME: SYRINGE PUMP ASSY

4 | SYRINGE HOLDER | SP-16 | 1
3 | ENDSTOP | SP-02 | 1
2 | PUMP BODY | SP-14 | 1
1 | PUSHER BLOCK | SP-15 | 1
NO. | DESCRIPTION | PART NO QTY

DRAWN BY: MAJ NEL | PROJECTION: | TASK/TASK NO. : M NEL THESIS

SOLIDWORKS Educational Product. For Instructional Use Only.

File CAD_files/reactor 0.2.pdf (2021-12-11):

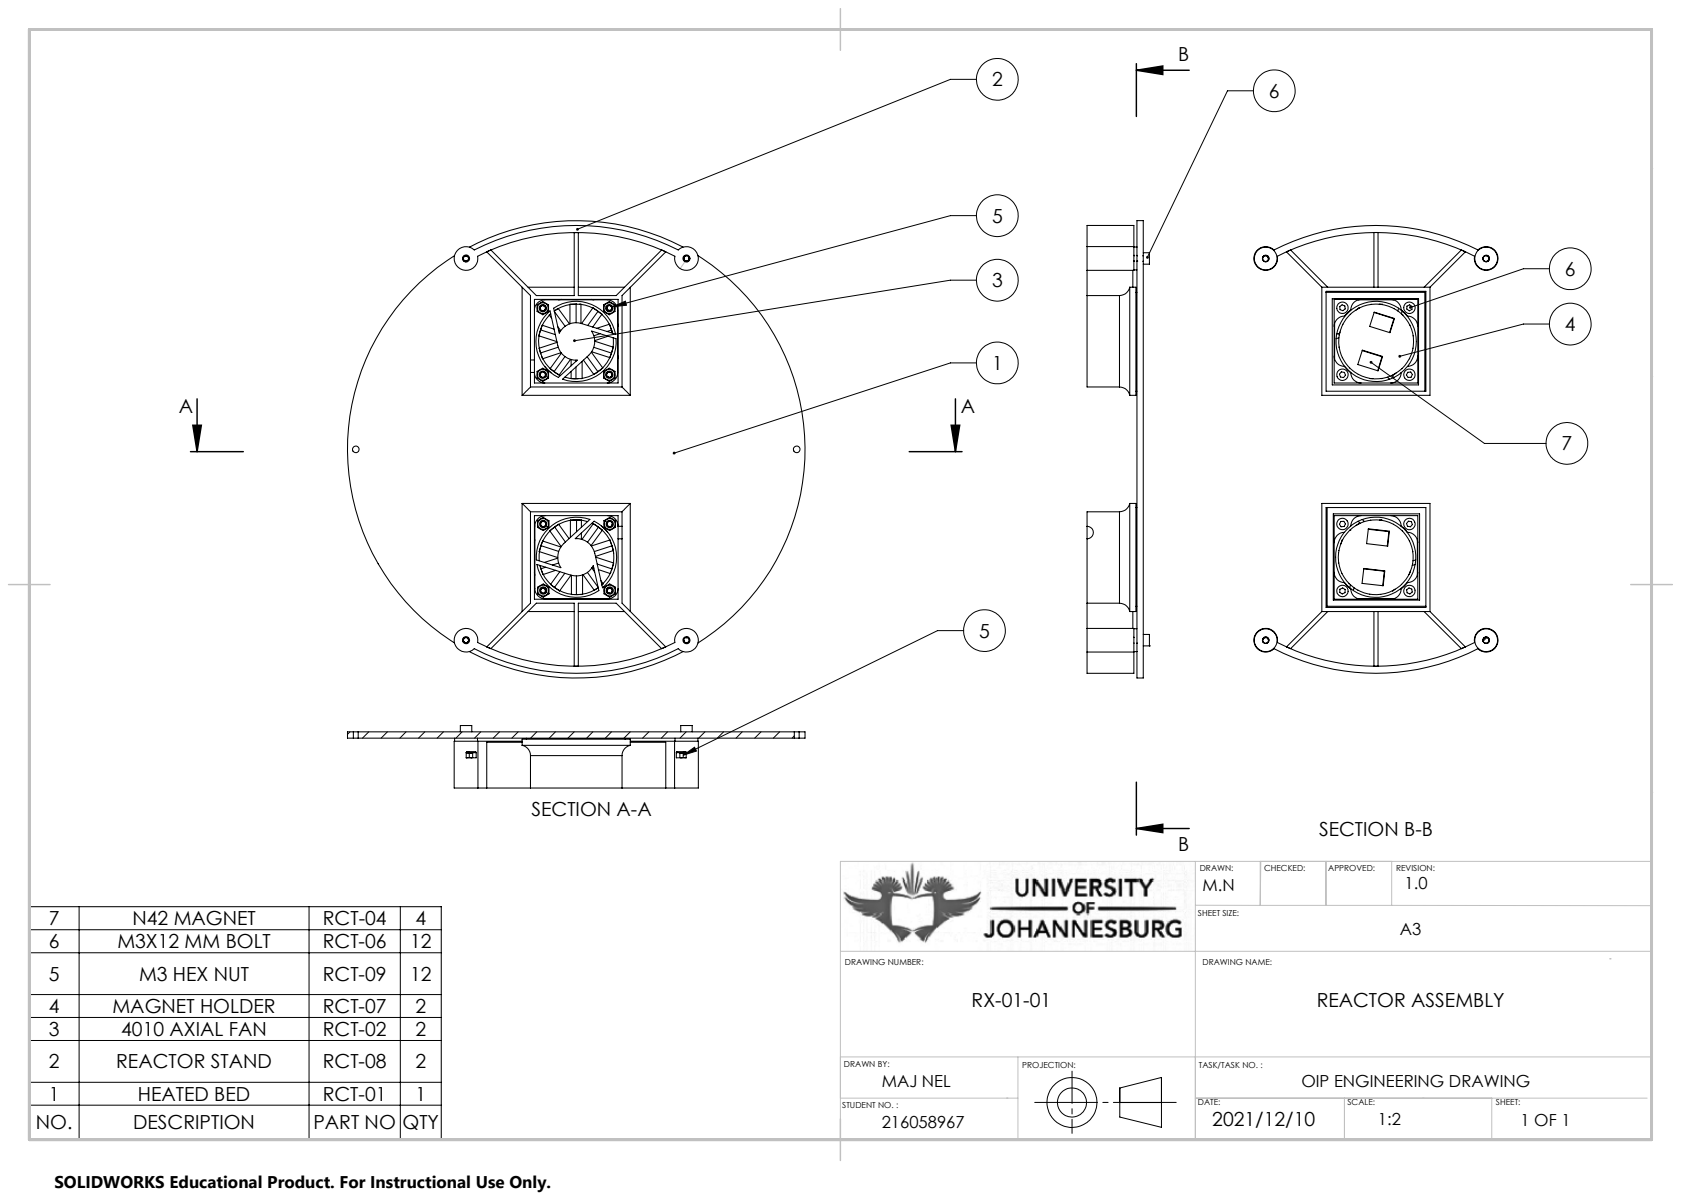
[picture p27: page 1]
SECTION A-A; SECTION B-B; DRAWN BY:; PROJECTION:; STUDENT NO. :; DRAWING NAME:; MAJ NEL; DRAWING NUMBER:; SHEET SIZE:; REACTOR ASSEMBLY

7 | N42 MAGNET | RCT-04 | 4
6 | M3X12 MM BOLT | RCT-06 | 12
5 | M3 HEX NUT | RCT-09 | 12
4 | MAGNET HOLDER | RCT-07 | 2
3 | 4010 AXIAL FAN | RCT-02 | 2
2 | REACTOR STAND | RCT-08 | 2
1 | HEATED BED | RCT-01 | 1
NO. | DESCRIPTION | PART NO QTY

TASK/TASK NO. :

OIP ENGINEERING DRAWING

SOLIDWORKS Educational Product. For Instructional Use Only.

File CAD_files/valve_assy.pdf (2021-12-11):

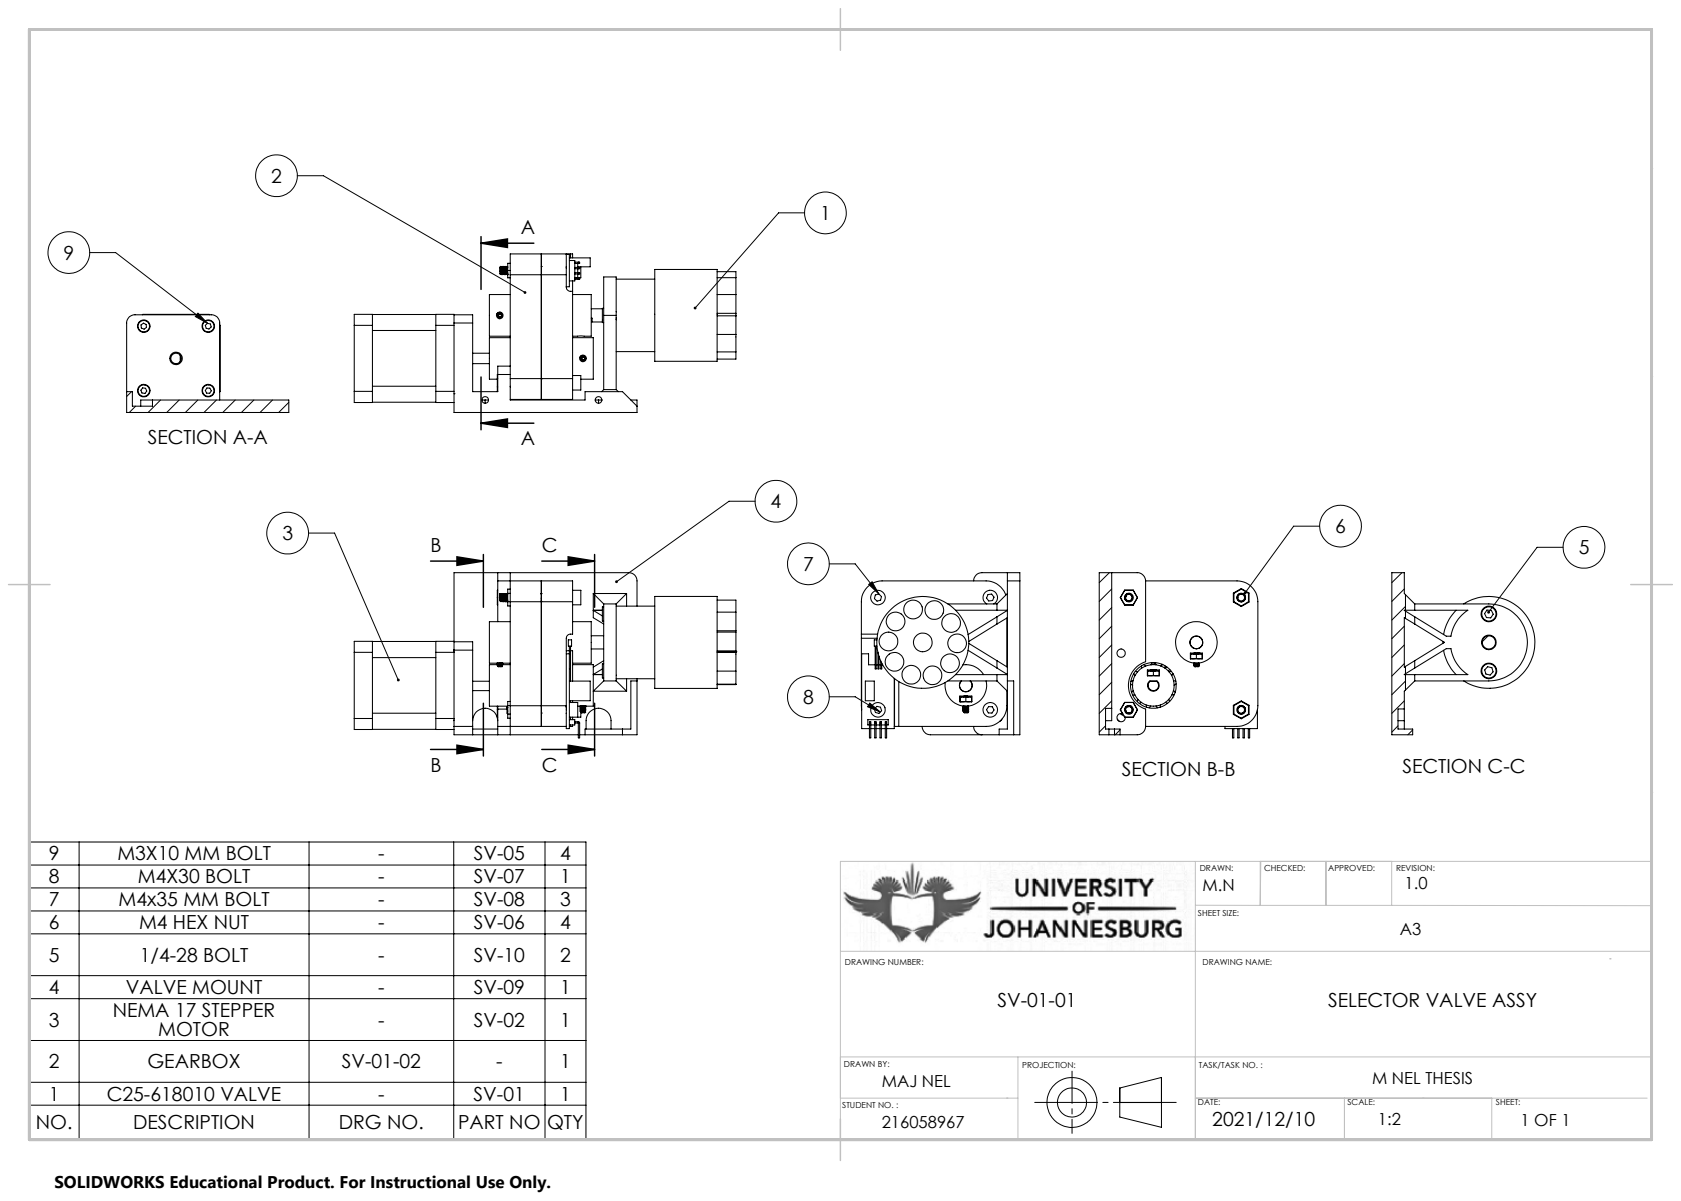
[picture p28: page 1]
SECTION A-A; SECTION B-B; SECTION C-C; M3X10 MM BOLT; M4X30 BOLT; STUDENT NO. :; SHEET SIZE:

7 | M4x35 MM BOLT | - | SV-08 | 3
6 | M4 HEX NUT | - | SV-06 | 4
5 | 1/4-28 BOLT | - | SV-10 | 2
4 | VALVE MOUNT | - | SV-09 | 1
3 | NEMA 17 STEPPER MOTOR | - | SV-02 | 1

DRAWING NUMBER: SV-01-01 | DRAWING NAME: SELECTOR VALVE ASSY

2 | GEARBOX | SV-01-02 | - | 1
1 | C25-618010 VALVE | - | SV-01 | 1
NO. | DESCRIPTION | DRG NO. | PART NO QTY

DRAWN BY: MAJ NEL | PROJECTION: | TASK/TASK NO. : M NEL THESIS

SOLIDWORKS Educational Product. For Instructional Use Only.

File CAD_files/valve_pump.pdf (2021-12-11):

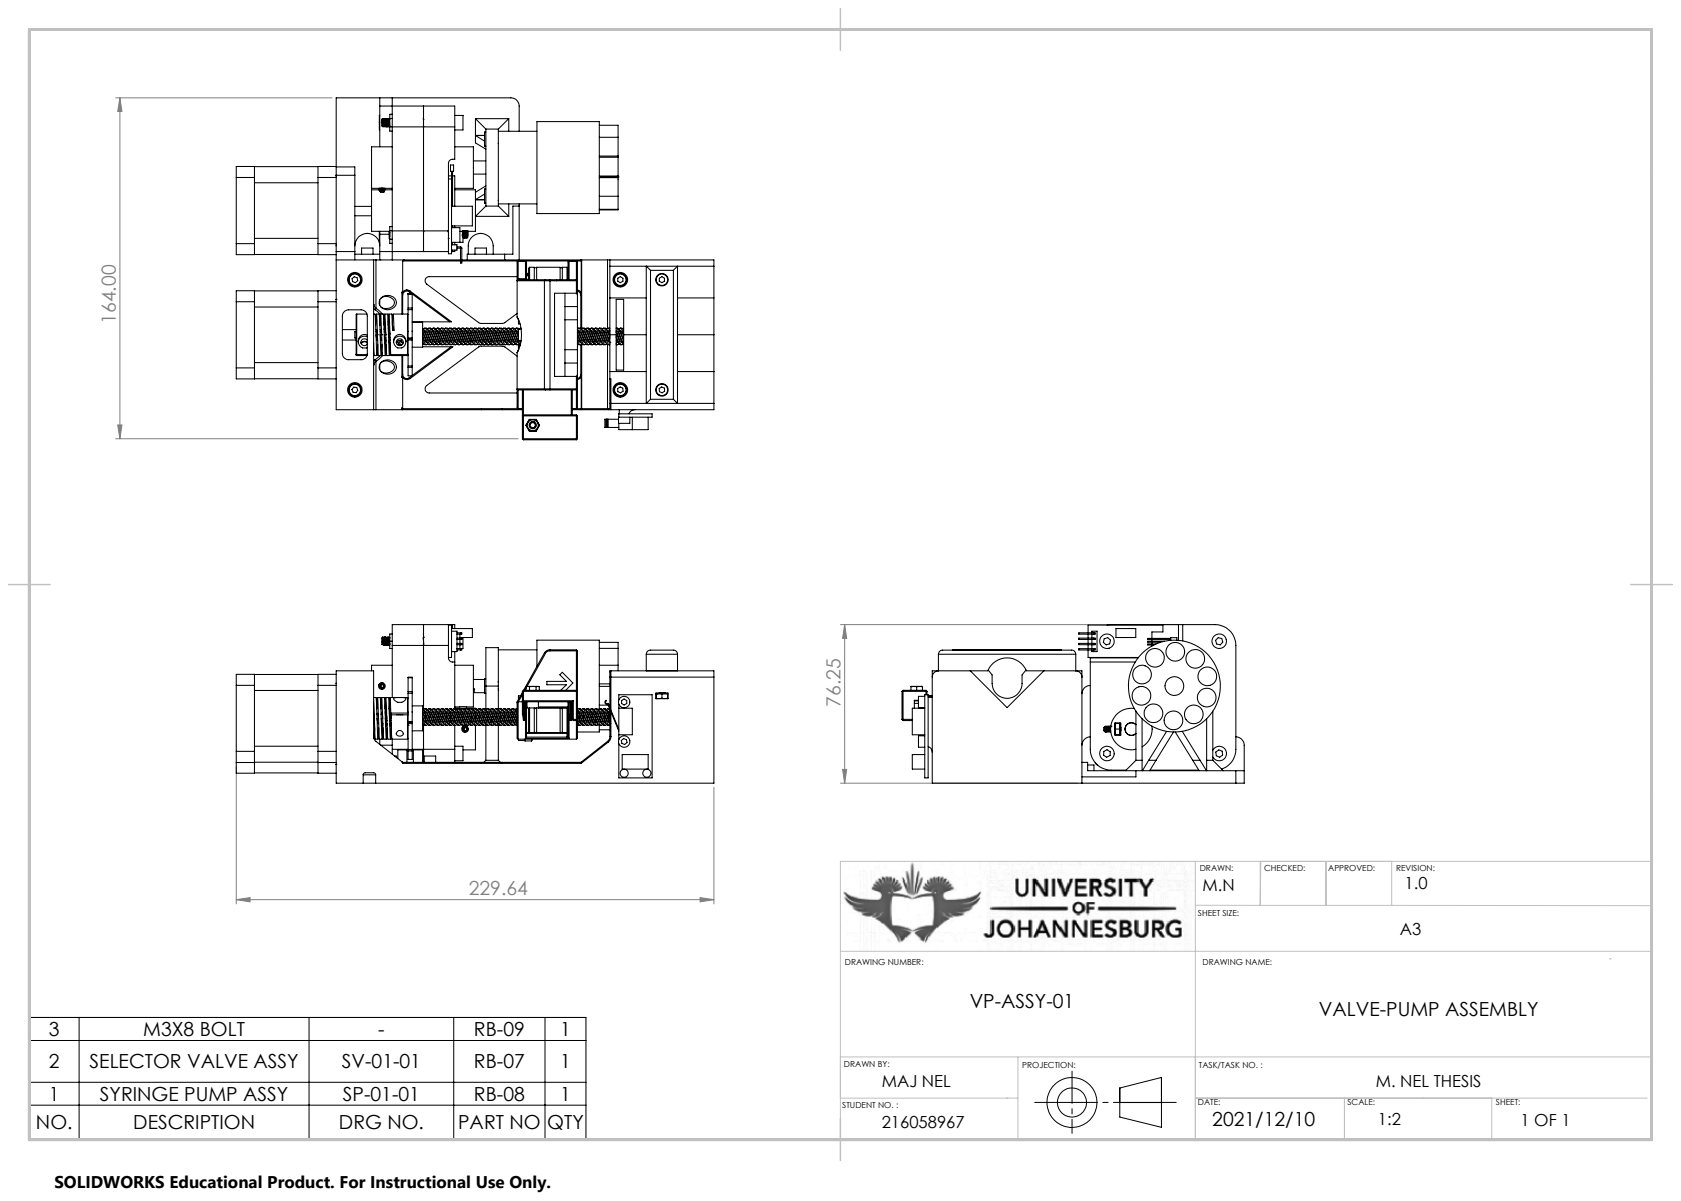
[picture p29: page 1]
STUDENT NO. :; SHEET SIZE:

DRAWING NUMBER: | DRAWING NAME: VALVE-PUMP ASSEMBLY VP-ASSY-01

3 | M3X8 BOLT | - | RB-09 | 1
2 | SELECTOR VALVE ASSY | SV-01-01 | RB-07 | 1
1 | SYRINGE PUMP ASSY | SP-01-01 | RB-08 | 1
NO. | DESCRIPTION | DRG NO. | PART NO QTY

DRAWN BY: MAJ NEL | PROJECTION: | TASK/TASK NO. : M. NEL THESIS

SOLIDWORKS Educational Product. For Instructional Use Only.

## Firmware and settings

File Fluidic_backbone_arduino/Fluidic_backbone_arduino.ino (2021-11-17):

/*
 Name:    Fluidic_backbone_arduino.ino
 Created: 2/1/2021 2:12:29 PM
 Author:  mattn
*/

//include core libraries
#include <CommandHandler.h>
#include <CommandManager.h>

//include module driver libraries
#include <AccelStepper.h>
#include <LinearAccelStepperActuator.h>
#include <CommandAnalogRead.h>
#include <CommandAnalogWrite.h>
#include <CommandAccelStepper.h>
#include <CommandLinearAccelStepperActuator.h>
#include <CommandDigitalWrite.h>
#include <CommandDigitalRead.h>

//motor encoder counters
void motor1Count();
void motor2Count();
int encoder1Pin = 18, encoder2Pin = 19;
int encoder1Count = 0, encoder2Count = 0;
int* encoder1 = &encoder1Count;
int* encoder2 = &encoder2Count;

CommandManager cmdMng;

//initialised module objects
AccelStepper stpx(AccelStepper::DRIVER, 54, 55);
CommandLinearAccelStepperActuator cmdStpx(stpx, 3, 38, encoder1);

AccelStepper stpy(AccelStepper::DRIVER, 60, 61);
CommandLinearAccelStepperActuator cmdStpy(stpy, 2, 56, encoder2);

AccelStepper stpz(AccelStepper::DRIVER, 46, 48);
CommandAccelStepper cmdStpz(stpz, 62, A3, 6400);

AccelStepper stpe0(AccelStepper::DRIVER, 26, 28);
CommandAccelStepper cmdStpe0(stpe0, 24, A4, 6400);

AccelStepper stpe1(AccelStepper::DRIVER, 36, 34);
CommandAccelStepper cmdStpe1(stpe1, 30);

CommandAnalogRead ar1(A3);
CommandAnalogRead ar2(A4);

CommandAnalogRead t1(A13);
CommandAnalogRead t2(A14);

//PWM pins
CommandAnalogWrite aw1(8);
CommandAnalogWrite aw2(9);

//Digital read pins
CommandDigitalRead dr1(63);
CommandDigitalRead dr2(59);

//Digital write pins
CommandDigitalWrite dw1(16);
CommandDigitalWrite dw2(17);


void setup() {
  //register modules with commandmanager
  Serial.begin(115200);
  cmdStpx.registerToCommandManager(cmdMng, "STPX");
  
  cmdStpy.registerToCommandManager(cmdMng, "STPY");
  
  cmdStpz.registerToCommandManager(cmdMng, "STPZ");
  cmdStpz.setMagThresholds(580, 490);
  
  cmdStpe0.registerToCommandManager(cmdMng, "STPE0");
  cmdStpe1.registerToCommandManager(cmdMng, "STPE1");

  ar1.registerToCommandManager(cmdMng, "AR1");
  ar2.registerToCommandManager(cmdMng, "AR2");

  t1.registerToCommandManager(cmdMng, "T1");
  t2.registerToCommandManager(cmdMng, "T2");

  aw1.registerToCommandManager(cmdMng, "AW1");
  aw2.registerToCommandManager(cmdMng, "AW2");

  dr1.registerToCommandManager(cmdMng, "DR1");
  dr2.registerToCommandManager(cmdMng, "DR2");
  
  attachInterrupt(digitalPinToInterrupt(encoder1Pin), motor1Count, RISING);
  attachInterrupt(digitalPinToInterrupt(encoder2Pin), motor2Count, RISING);
  cmdMng.init();
}

void loop() {
  cmdMng.update();
}

void motor1Count(){
  encoder1Count ++;
}

void motor2Count(){
  encoder2Count ++;
}

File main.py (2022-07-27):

"""
 This script can be used to start the robot with or without a GUI.
 By default the program will create logs in the directory where this script is found
 in a folder called "logs". To change the destination folder, simply change the 
 script_dir variable. 
"""

import datetime
import logging
import os
from UJ_FB import FluidicBackbone


script_dir = os.path.dirname(__file__)
if not os.path.exists(os.path.join(script_dir, "logs")):
    os.chdir(script_dir)
    os.mkdir("logs")
logfile = 'logs/log' + datetime.datetime.today().strftime('%Y%m%d')
logfile = os.path.join(script_dir, logfile)
logging.basicConfig(filename=logfile, level=logging.INFO)

# Start the robot with a GUI:
robot = FluidicBackbone(gui=True, web_enabled=False, simulation=True)

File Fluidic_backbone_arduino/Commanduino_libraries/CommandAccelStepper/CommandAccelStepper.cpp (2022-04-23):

#include "CommandAccelStepper.h"

void* globalCommandAccelStepperPt2Object;

CommandAccelStepper::CommandAccelStepper(AccelStepper &myStepper, int myEnablePin, int myHeSensor, int myStepsPerRev)
{
    moving = false;

    stepper = &myStepper;
    hePin = myHeSensor;
    stepsPerRev = myStepsPerRev;
    stepsPerPort = stepsPerRev/10;

    stepper->setSpeed(5000);
    stepper->setMaxSpeed(5000);
    stepper->setAcceleration(2000);
    enableAcceleration();

    stepper->setEnablePin(myEnablePin);
    stepper->setPinsInverted(false, false, true);
    stepper->disableOutputs();
}

/**
* Register to Command Manager
*/
void CommandAccelStepper::registerToCommandManager(CommandManager &cmdMgr, const char *command)
{
    cmdMgr.addDevice(command, this, wrapper_init, wrapper_handleCommand, wrapper_setHeader, wrapper_update);
}

/**
* Init function to be run once in setup.
* We initialise all the callback here
* Wrapper is used by CommandManager
*/
void CommandAccelStepper::wrapper_init(void* pt2Object)
{
    CommandAccelStepper* self = (CommandAccelStepper*) pt2Object;
    self->init();
}

void CommandAccelStepper::init()
{
    #ifdef COMMANDACCELSTEPPER_DEBUG
        Serial.println("Init CommandAccelStepper");
    #endif

    //do device init first

    //Register all commands.
    //ALL OF THEM
    cmdHdl.addCommand(BONJOUR_CMD, wrapper_bonjour);

    cmdHdl.addCommand(COMMANDACCELSTEPPER_SET_POSITION, wrapper_setCurrentPosition);
    cmdHdl.addCommand(COMMANDACCELSTEPPER_SET_SPEED, wrapper_setSpeed);
    cmdHdl.addCommand(COMMANDACCELSTEPPER_SET_MAX_SPEED, wrapper_setMaxSpeed);
    cmdHdl.addCommand(COMMANDACCELSTEPPER_SET_ACC, wrapper_setAcceleration);

    cmdHdl.addCommand(COMMANDACCELSTEPPER_ENABLE_ACC, wrapper_enableAcceleration);
    cmdHdl.addCommand(COMMANDACCELSTEPPER_DISABLE_ACC, wrapper_disableAcceleration);

    cmdHdl.addCommand(COMMANDACCELSTEPPER_MOVE_TO, wrapper_moveTo);
    cmdHdl.addCommand(COMMANDACCELSTEPPER_MOVE, wrapper_move);
    cmdHdl.addCommand(COMMANDACCELSTEPPER_STOP, wrapper_stop);

    cmdHdl.addCommand(COMMANDACCELSTEPPER_REQUEST_DIST, wrapper_distanceToGo);
    cmdHdl.addCommand(COMMANDACCELSTEPPER_REQUEST_TARGET, wrapper_targetPosition);
    cmdHdl.addCommand(COMMANDACCELSTEPPER_REQUEST_POSITION, wrapper_currentPosition);
    cmdHdl.addCommand(COMMANDACCELSTEPPER_REQUEST_MOVING, wrapper_isMoving);

    cmdHdl.addCommand(COMMANDACCELSTEPPER_REQUEST_SPEED, wrapper_speed);
    cmdHdl.addCommand(COMMANDACCELSTEPPER_REQUEST_MAXSPEED, wrapper_maxSpeed);
    cmdHdl.addCommand(COMMANDACCELSTEPPER_REQUEST_ACCELERATION, wrapper_acceleration);

    //Default one
    cmdHdl.setDefaultHandler(wrapper_unrecognized);
}

/**
* Handling messages
* wrapper is used by CommandManager
*/
void CommandAccelStepper::wrapper_handleCommand(const char *command, void* pt2Object)
{
    //Each time the handleCommand is called, it is given the command and the pointer to the instance that should handle it
    globalCommandAccelStepperPt2Object = pt2Object;
    //Cast it to class name
    CommandAccelStepper* self = (CommandAccelStepper*) globalCommandAccelStepperPt2Object;

    self->handleCommand(command);
}

void CommandAccelStepper::handleCommand(const char *command)
{
    #ifdef COMMANDACCELSTEPPER_DEBUG
        Serial.print("Device received: ");
        Serial.println(command);
    #endif

    cmdHdl.processString(command);
}

/**
* Set Header for the message that comes out of the Device
* The wrapper is used by the CommandManager
*/
void CommandAccelStepper::wrapper_setHeader(const char *cmdHeader, void* pt2Object)
{
    //Explicitly cast to a pointer to classname
    CommandAccelStepper* self = (CommandAccelStepper*) pt2Object;
    self->setHeader(cmdHeader);
}

void CommandAccelStepper::setHeader(const char *cmdHeader)
{
    #ifdef COMMANDACCELSTEPPER_DEBUG
        Serial.print("Set Header CommandAccelStepper to ");
        Serial.println(cmdHeader);
    #endif

    cmdHdl.setCmdHeader(cmdHeader);
}

/**
* Update function to be run each loop
* The wrapper is used by the CommandManager
*/
void CommandAccelStepper::wrapper_update(void* pt2Object)
{
    //Cast to pointer of classname
    CommandAccelStepper* self = (CommandAccelStepper*) pt2Object;
    self->update();
}

/*
* Update function: Called numerous times per second
*/
void CommandAccelStepper::update()
{
    curTime = millis();
    if(accelerationEnabled)
    {
        stepper->run();
    }
    else
    {
        stepper->runSpeedToPosition();
    }
    if (!moving && !subsMoves){
        if (!moveCompleteSent){
            moveCompleteUpdate();
        }
        if ((curTime - stopTime) > 5000){
            stepper->disableOutputs();
        }
    }
    distanceLeft = stepper->distanceToGo();
    //Check HE sensor at each port position for positioning movements
    if (subsMoves && distanceLeft == 0){
        //valve has reached end of current move
        checkHeSensor();
        posCount++;
        if (posCount < numPositions){
            if (fwd){
				stepper->move(stepsPerPort);
                if (!accelerationEnabled)
                    stepper->setSpeed(lastSetSpeed);
            }else{
				stepper->move(-stepsPerPort);
                if (!accelerationEnabled)
                    stepper->setSpeed(lastSetSpeed);
            }
        }else {
            subsMoves = false;
        }
    }
    if(distanceLeft == 0 && !subsMoves)
    {
        if (moving){
            stopTime = millis();
        }
        moving = false;
    }
}

/**
* A Bonjour behaviour eenable to know who we are talking to
* change the CommandAccelStepper_BONJOUR_ID  and ensure it is unique to your new device
* keep CommandAccelStepper_BONJOUR_ID short
* DONT FORGET TO CHANGE THE NAME OF THIS VARIABLE APPROPRIATELY!!
*/
void CommandAccelStepper::wrapper_bonjour()
{
    //Cast once more...
    CommandAccelStepper* self = (CommandAccelStepper*) globalCommandAccelStepperPt2Object;
    self->bonjour();
}

void CommandAccelStepper::bonjour()
{
    #ifdef COMMANDACCELSTEPPER_DEBUG
        Serial.println("Device received bonjour command");
    #endif

    cmdHdl.initCmd();
    cmdHdl.addCmdString(BONJOUR_CMD);
    cmdHdl.addCmdDelim();
    cmdHdl.addCmdString(COMMANDACCELSTEPPER_BONJOUR_ID);
    cmdHdl.addCmdTerm();
    cmdHdl.sendCmdSerial();
}

/**
* Default unrecognized command and wrapper
* Respond a message with header "?" and the command received as the argument
*/
void CommandAccelStepper::wrapper_unrecognized(const char *command)
{
    CommandAccelStepper* self = (CommandAccelStepper*) globalCommandAccelStepperPt2Object;
    self->unrecognized(command);
}

void CommandAccelStepper::unrecognized(const char *command)
{
    cmdHdl.initCmd();
    cmdHdl.addCmdString(UNRECOGNIZED_CMD);
    cmdHdl.addCmdDelim();
    cmdHdl.addCmdString(command);
    cmdHdl.addCmdTerm();
    cmdHdl.sendCmdSerial();
}
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

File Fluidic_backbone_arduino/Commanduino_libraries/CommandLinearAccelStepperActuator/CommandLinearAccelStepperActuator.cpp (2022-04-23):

#include "CommandLinearAccelStepperActuator.h"

void* globalCommandLinearAccelStepperActuatorPt2Object;

CommandLinearAccelStepperActuator::CommandLinearAccelStepperActuator(AccelStepper &mystepper, int myHomeSwitchPin, int myEnablePin, int* myEncoderCount) {

  LinearAccelStepperActuator my_linearactuator = LinearAccelStepperActuator(mystepper, myHomeSwitchPin, myEnablePin, myEncoderCount);

  linearactuator = my_linearactuator;
}

/**
* register to a CommandManager
*/
void CommandLinearAccelStepperActuator::registerToCommandManager(CommandManager &cmdMng, const char *command) {
  cmdMng.addDevice(command, this, wrapper_init, wrapper_handleCommand, wrapper_setHeader, wrapper_update);
}

/**
* init function to be run one in setup
* we initialize all the callback here
* the wrapper is used by CommandManager
*/
void CommandLinearAccelStepperActuator::wrapper_init(void* pt2Object) {
  // explicitly cast to a pointer to Classname
  CommandLinearAccelStepperActuator* self = (CommandLinearAccelStepperActuator*) pt2Object;
  self->init();
}

void CommandLinearAccelStepperActuator::init() {
  #ifdef COMMANDLINEARACCELSTEPPER_DEBUG
    Serial.println("Init CommandLinearAccelStepperActuator");
  #endif

  //do you device init first
  linearactuator.init();

  // here register all the commands
  // this is a simple ping behavior to demo
  // here register all the commands
  // the following is mandatory for the bonjour behavior
  cmdHdl.addCommand(BONJOUR_CMD, wrapper_bonjour);

  cmdHdl.addCommand(COMMANDLINEARACCELSTEPPER_SET_POSITION, wrapper_setCurrentPosition);
  cmdHdl.addCommand(COMMANDLINEARACCELSTEPPER_SET_SPEED, wrapper_setSpeed);
  cmdHdl.addCommand(COMMANDLINEARACCELSTEPPER_SET_MAX_SPEED, wrapper_setMaxSpeed);
  cmdHdl.addCommand(COMMANDLINEARACCELSTEPPER_SET_ACC, wrapper_setAcceleration);

  cmdHdl.addCommand(COMMANDLINEARACCELSTEPPER_ENABLE_ACC, wrapper_enableAcceleration);
  cmdHdl.addCommand(COMMANDLINEARACCELSTEPPER_DISABLE_ACC, wrapper_disableAcceleration);
  cmdHdl.addCommand(COMMANDLINEARACCELSTEPPER_ENABLE_SWITCH, wrapper_enableRevertedSwitch);
  cmdHdl.addCommand(COMMANDLINEARACCELSTEPPER_DISABLE_SWITCH, wrapper_disableRevertedSwitch);

  cmdHdl.addCommand(COMMANDLINEARACCELSTEPPER_HOME, wrapper_home);
  cmdHdl.addCommand(COMMANDLINEARACCELSTEPPER_MOVE_TO, wrapper_moveTo);
  cmdHdl.addCommand(COMMANDLINEARACCELSTEPPER_MOVE, wrapper_move);
  cmdHdl.addCommand(COMMANDLINEARACCELSTEPPER_STOP, wrapper_stop);

  cmdHdl.addCommand(COMMANDLINEARACCELSTEPPER_REQUEST_SWITCH, wrapper_homeSwitchState);
  cmdHdl.addCommand(COMMANDLINEARACCELSTEPPER_REQUEST_MOVING, wrapper_isMoving);
  cmdHdl.addCommand(COMMANDLINEARACCELSTEPPER_REQUEST_DIST, wrapper_distanceToGo);
  cmdHdl.addCommand(COMMANDLINEARACCELSTEPPER_REQUEST_TARGET, wrapper_targetPosition);
  cmdHdl.addCommand(COMMANDLINEARACCELSTEPPER_REQUEST_POSITION, wrapper_currentPosition);

  cmdHdl.addCommand(COMMANDLINEARACCELSTEPPER_REQUEST_SPEED, wrapper_speed);
  cmdHdl.addCommand(COMMANDLINEARACCELSTEPPER_REQUEST_MAXSPEED, wrapper_maxSpeed);
  cmdHdl.addCommand(COMMANDLINEARACCELSTEPPER_REQUEST_ACCELERATION, wrapper_acceleration);

  // a default one is provided in the example
  cmdHdl.setDefaultHandler(wrapper_unrecognized);

}

/**
* handling messages
* the wrapper is used by CommandManager
*/
void CommandLinearAccelStepperActuator::wrapper_handleCommand(const char *command, void* pt2Object) {
  // each time the handleCommand is called, it is given the command and the pointer to the instance that should handle it
  globalCommandLinearAccelStepperActuatorPt2Object = pt2Object;
  // explicitly cast to a pointer to Classname
  CommandLinearAccelStepperActuator* self = (CommandLinearAccelStepperActuator*) globalCommandLinearAccelStepperActuatorPt2Object;

  self->handleCommand(command);
}

void CommandLinearAccelStepperActuator::handleCommand(const char *command) {
  #ifdef COMMANDLINEARACCELSTEPPER_DEBUG
    Serial.print("Device received: ");
    Serial.println(command);
  #endif

  cmdHdl.processString(command);
}


/**
* set Header for the message that come out of this device
* the wrapper is used by CommandManager
*/
void CommandLinearAccelStepperActuator::wrapper_setHeader(const char *cmdHeader, void* pt2Object) {
  // explicitly cast to a pointer to Classname
  CommandLinearAccelStepperActuator* self = (CommandLinearAccelStepperActuator*) pt2Object;
  self->setHeader(cmdHeader);
}

void CommandLinearAccelStepperActuator::setHeader(const char *cmdHeader) {
  #ifdef COMMANDLINEARACCELSTEPPER_DEBUG
    Serial.print("Set Header CommandLinearAccelStepperActuator to ");
    Serial.println(cmdHeader);
  #endif

  cmdHdl.setCmdHeader(cmdHeader);
}

/**
* update function to be run each loop
* the wrapper is used by CommandManager
*/
void CommandLinearAccelStepperActuator::wrapper_update(void* pt2Object) {
  // explicitly cast to a pointer to Classname
  CommandLinearAccelStepperActuator* self = (CommandLinearAccelStepperActuator*) pt2Object;
  self->update();
}

void CommandLinearAccelStepperActuator::update() {
  // do whatever you need to do here, non-blocking things!!
  // update should be fast
  linearactuator.update();

  if ((!moveCompleteSent) && (!linearactuator.isMoving())){
    moveCompleteSent = true;
    moveCompleteUpdate();
  }
  if ((!switchStateSent) && (linearactuator.isMoving())){
    if (millis() - lastSwitchCheckTime > 1000){
      if (linearactuator.homeSwitchState() == HIGH){
        switchStateSent = true;
        switchStateUpdate();
      }
    }
  }
}


/*
* a bonjour behavior enable to know who we are talking to
* change the COMMANDLINEARACCELSTEPPER_BONJOUR_ID and ensure it is unique to your new device
* keep COMMANDLINEARACCELSTEPPER_BONJOUR_ID short
* do not forget to change the name of this variable appropriately
*/
void CommandLinearAccelStepperActuator::wrapper_bonjour()
{
  // explicitly cast to a pointer to Classname
  CommandLinearAccelStepperActuator* self = (CommandLinearAccelStepperActuator*) globalCommandLinearAccelStepperActuatorPt2Object;
  self->bonjour();
}

void CommandLinearAccelStepperActuator::bonjour() {
  #ifdef COMMANDLINEARACCELSTEPPER_DEBUG
    Serial.println("Device received bonjour command");
  #endif

  cmdHdl.initCmd();
  cmdHdl.addCmdString(BONJOUR_CMD);
  cmdHdl.addCmdDelim();
  cmdHdl.addCmdString(COMMANDLINEARACCELSTEPPER_BONJOUR_ID);
  cmdHdl.addCmdTerm();
  cmdHdl.sendCmdSerial();
}

/**
* default unrecognized command and wrapper
* respond a message with header "?" and the command received as argument
*/
void CommandLinearAccelStepperActuator::wrapper_unrecognized(const char *command) {
  // explicitly cast to a pointer to Classname
  CommandLinearAccelStepperActuator* self = (CommandLinearAccelStepperActuator*) globalCommandLinearAccelStepperActuatorPt2Object;
  self->unrecognized(command);
}
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

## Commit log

2021-01-27 Manager: Added discrete command syringe and command valve methods to. Added method to check connections. Added additional popup to syringe homing to warn of emptying syringe.
2021-02-02 Added serial lock to avoid sending simultaneous serial commands
    [GUI.py]
2021-02-15 Added setup program to populate JSON config files automatically. Added additional asynchronous support to manager. Fixed homing and movement with linear accelstepper
    [setup_GUI.py]
2021-02-17 Fixed movement. Steppers now respond to commands sent. Added jog functionality
    [setup_GUI.py]
2021-02-19 Changed valve movement and homing algorithm. Moved motor watchdog function into StepperMotor class.
2021-03-04 Incorporated networkx graphing into manager.py. Added prototype functionality to move liquids from one flask to another to Manager.py Manager now uses queuing module to schedule actions. Added connec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
2021-03-05 Added valve jog menu to Fluidic_backbone_GUI.py. Added jog method to selectorValve.py
2021-03-05 Valve image
2021-03-08 Added support to setup_GUI.py for geared motors. Added geared motors to selectorValve.py.
2021-03-09 Added function to send messages to GUI in Module.py. Changed jog valve to send custom amounts of steps. Cleaned up command_module logic in Manager.py.
2021-03-11 Cleaned up command_modules method in Module.py. Added pathfinding for single valve systems. Added check for zero pumps on startup. Aligned SyringePump and FBFlask classes change_vol and change_conten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
    [setup_GUI.py]
2021-03-15 Bug fixes to move_liquid
    [setup_GUI.py]
2021-03-15 Fixed aspirate/withdraw in GUI to correctly indicate direction. Changed homing algorithm in selectorValve.py. Small fixes to code.
2021-03-16 Bug fixes to transfer between flasks.
    [setup_GUI.py]
2021-03-29 Add files via upload
    added Arduino sketches
2021-04-09 added TempSensor and MagStirrer classes to devices.py. Added override buttons to Fluidic_backbone_GUI.py. Users can now pause or stop the robot during operation. Overhauled the interrupt system in Ma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
2021-06-03 Overhauled movement algorithm in Manager.py to handle multiple pumps and valves. Added simple command queuing console interface to test simple reaction setups. Numerous small changes to fix bugs
    [setup_GUI.py]
2021-06-21 Bug fixes to setup function and movement. Reactors now have proper dual link in graph. Volume checked now correctly updates attached modules. setup_GUI.py now adds all motors regardless of whether th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
    [Fluidic_backbone_arduino.ino, setup_GUI.py, web_listener.py]
2021-06-23 Moved all stepper motor enabling on to the Firmware. Removed related functions from stepperMotor.py. If motors require holding torque on syringe pumps (backpressure considerations) the LinearAccelSte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
    [project.cfg]
2021-08-02 Added preheating support and waiting for target temperature to reactor.py. Debugged selectorValve.py homing. Debugged pause/resume functions.
2021-08-04 Added new todos for camera setup
2021-08-17 Modified reactor.py to run a continuous thread. Added xdl support to web_listener.
2021-08-24 Fixed arduino file
2021-09-19 Changed magnet search move distance. Updated setup GUI to reflect different motor setups for pumps and valves
2021-09-29 added magnet counting to selectorvalve. Bug fixes
    [Fluidic_backbone_arduino.ino, fluidic_backbone_gui.py, main.py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]
2021-10-30 dev push for dead volume fix
    [fluidic_backbone_gui.py, selectorvalve.py, setup_GUI.py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]
2021-11-01 Added backlash support for syringe pump. Bug fixes on dead volume.
    [fluidic_backbone_gui.py, selectorvalve.py, syringepump.py]
2021-11-04 bug fixes for reactor and selector valve
    [CommandAccelStepper.cpp, CommandAccelStepper.h, CommandLinearAccelStepperActuator.cpp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]
2021-11-05 Bug fixes. Added timestamp to logs
    [selectorvalve.py, web_listener.py]
2021-11-08 Added temperature indicator to GUI. Added method of queueing XDL without the server. Added ability to debug the robot when an error occurs.
    [fluidic_backbone_gui.py, selectorvalve.py, web_listener.py]
2021-11-13 Added dead volume compensation for transfers. Overhauled logging to be more descriptive. Bug fixes on camera and image sending.
    [CommandAccelStepper.cpp, fluidic_backbone_gui.py, selectorvalve.py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]
2021-11-14 Bug fixes for raspberry pi
    [setup_GUI.py, web_listener.py]
2021-11-14 bug fixes. Set valves to constant speed mode
    [selectorvalve.py, setup_GUI.py, web_listener.py]
2021-11-15 constant speed valve stepper
2021-11-15 Added means to recover from valve positioning error.
    [CommandAccelStepper.cpp, selectorvalve.py, syringepump.py]
2021-11-15 Fixed issue where tkinter wouldn't close
    [fluidic_backbone_gui.py, main.py, selectorvalve.py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]
2021-11-15 Updated commandaccelstepper to allow encoder calibration
2021-11-17 Added thread to Camera class to clear frame buffer
2021-11-17 camera fixes
2021-11-18 More camera issues...
2021-11-18 fixed ip address issue on unix
    [web_listener.py]
2021-11-19 added default flow overrides and extra dead volume push
2021-11-20 added flag to pause after current reaction
2021-11-23 fixed issue with reagent name comparison
2021-12-11 Thesis commit with CAD files
    [6mm rod 21mm.SLDPRT, 6mm rod.SLDPRT, 8-32-8.SLDPRT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]
2022-02-01 added support for clusterbot as sample storage
2022-02-03 Debugged sample storage
2022-03-04 Packaged module to be installed using pip. Fixed an issue where GUI wouldn't close when using the command line.
    [fluidic_backbone_gui.py, main.py]
2022-03-31 Fixed bug where config files would not be created on machines where UJ_FB is installed to site-packages.
    [main.py, setup_GUI.py]
2022-04-01 Bug fixes. Restructured GUI to quit properly.
    [fluidic_backbone_gui.py, main.py, setup_GUI.py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]
2022-04-01 Fixed bug with start auto execution button
    [fluidic_backbone_gui.py, main.py]
2022-04-01 Fixed bug with syringe transfers and creating command dictionaries with Module objects as "target" rather than the name (str).
    [main.py, web_listener.py]
2022-04-04 bug fixes to module type names
    [fluidic_backbone_gui.py, main.py, syringepump.py]
2022-04-12 Finalised syringe-syringe transfers. Bug fixes from testing. Documentation overhaul. Added new functionality to commanduino.
    [CommandLinearAccelStepperActuator.cpp, CommandLinearAccelStepperActuator.h, LinearAccelStepperActuator.cpp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]
2022-04-13 fixed location of script_dir in fluidicbackbone.py.
    [fluidicbackbone.py]
2022-07-02 UI updates and bug fixes
    [fluidic_backbone_gui.py, setup_GUI.py]
